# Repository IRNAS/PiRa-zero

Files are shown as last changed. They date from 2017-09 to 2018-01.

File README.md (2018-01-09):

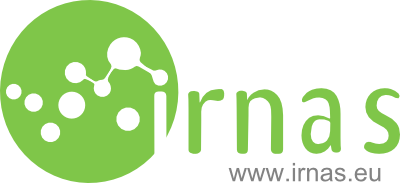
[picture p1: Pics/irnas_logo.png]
irnas_logo

# PiRA zero 
## Power in Responsive Applications HAT for Raspberry Pi with RTC for power saving mode

PiRa zero is a compact shield for power scheduling on Rasppbery Pi and similar devices in solar and wirelessly powered applications. It implements the following key features:

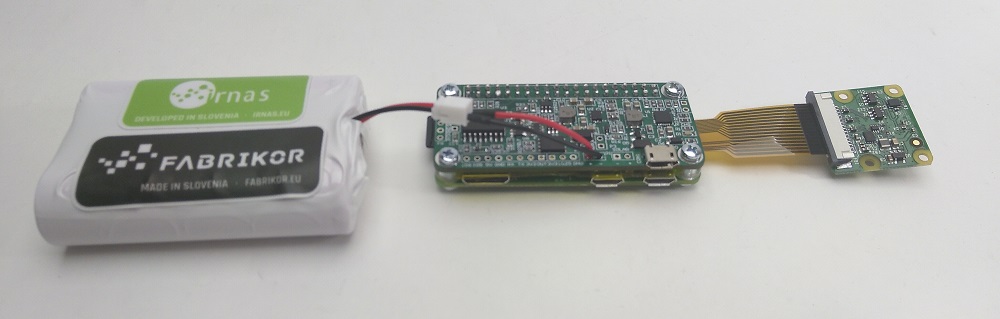
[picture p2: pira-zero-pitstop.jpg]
pira_image


## Features

* single cell LiPo cell charging of up to 3A (multiple 18650 cells supported) + LifePo4 support
* solar panel charging (Voltaic systems 6W panels in parallel recommended)
* USB charging, compatible with QI wireless chargers
* advanced current limiting, to support wide array of chargers
* precise charging control via i2c (BQ24296)
* battery temperature protection with thermistor
* battery reverse polarity protection and fuse (3A)
* high-current battery output mosfet (for 3G or satellite modems)
* LORA RMF95 communication module
* battery voltage precise measurement (MCP3021)
* advanced power scheduling for robust applications:
  * power timer TPL5110 for configurable scheduled boot 1s-7200s or one-time power up on charging
  * S3231 for configurable scheduled boot and timekeeping
  * nfigurable power-up sources
  * ower-up on charging
  * ower-up from power timer
  * ower-up from RTC
  * ower-up from self-enable (external CPU signal)
 
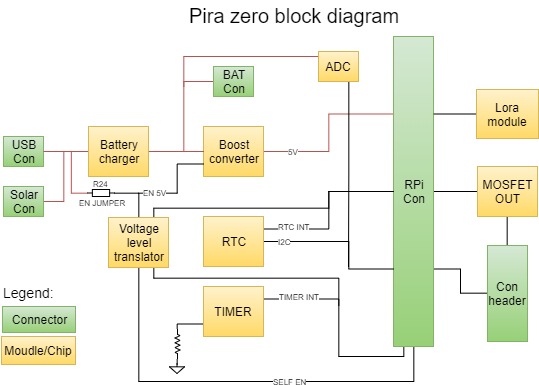
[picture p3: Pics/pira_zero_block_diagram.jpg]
pira_block_diagram


## Connector pinout

 * All ground pins connected, UART, SPI pins connected
 * Pin 1 - 3V3 - from Pi to board
 * Pin 2 - 5V - from board to Pi
 * Pin 3 - SDA
 * Pin 4 - 5V - from board to Pi
 * Pin 5 - SCL
 * Pin 7 - BCM 4 - RTC-Reset- output, reset RTC if needed
 * Pin 11 - BCM 17 - Timer-EN - input, detect wake-up from RTC
 * Pin 12 - BCM 18 - CPU self-enable - output, keep high until shutdown
 * Pin 13 - BCM 27 - Timer done - output, set high to signal timer to power off
 * Pin 15 - BCM 22 - RTC-EN - input, detect wake-up from RTC
 * Pin 16 - BCM 23 - GPO-FET - output, enable mosfet output
 * Pin 22 - BCM 25 - GPIO BCM25 - available at header
 * Pin 29 - BCM 5 - GPIO BCM 5 - available at header
 * Pin 31 - BCM 6 - GPIO BCM 6 - available at header
 * Pin 33 - BCM 13 - LORA reset

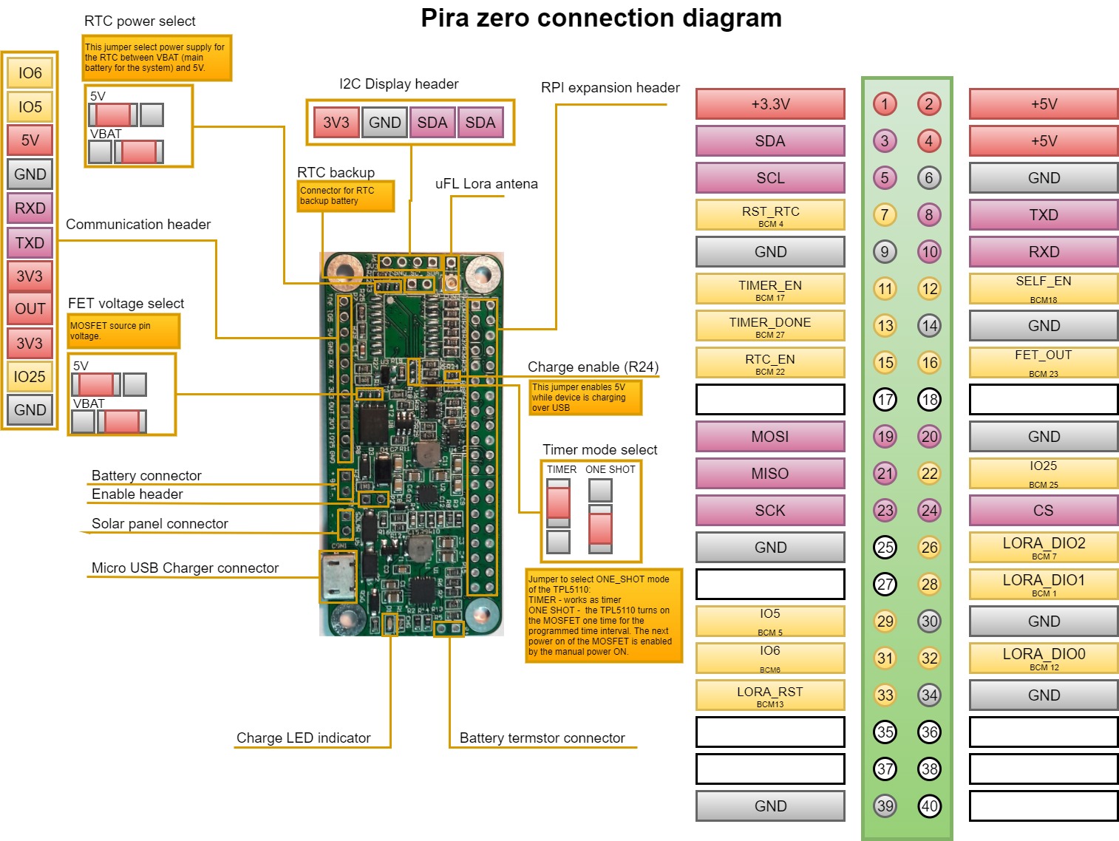
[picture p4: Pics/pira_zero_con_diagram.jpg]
pira_zero_con_diagram


## Power consumption
TODO

---

#### License

All our projects are as usefully open-source as possible.

Hardware including documentation is licensed under [CERN OHL v.1.2. license](http://www.ohwr.org/licenses/cern-ohl/v1.2)

Firmware and software originating from the project is licensed under [GNU GENERAL PUBLIC LICENSE v3](http://www.gnu.org/licenses/gpl-3.0.en.html).

Open data generated by our projects is licensed under [CC0](https://creativecommons.org/publicdomain/zero/1.0/legalcode).

All our websites and additional documentation are licensed under [Creative Commons Attribution-ShareAlike 4 .0 Unported License](https://creativecommons.org/licenses/by-sa/4.0/legalcode).

What this means is that you can use hardware, firmware, software and documentation without paying a royalty and knowing that you'll be able to use your version forever. You are also free to make changes but if you share these changes then you have to do so on the same conditions that you enjoy.

Koruza, GoodEnoughCNC and IRNAS are all names and marks of Institut IRNAS Rače. 
You may use these names and terms only to attribute the appropriate entity as required by the Open Licences referred to above. You may not use them in any other way and in particular you may not use them to imply endorsement or authorization of any hardware that you design, make or sell.

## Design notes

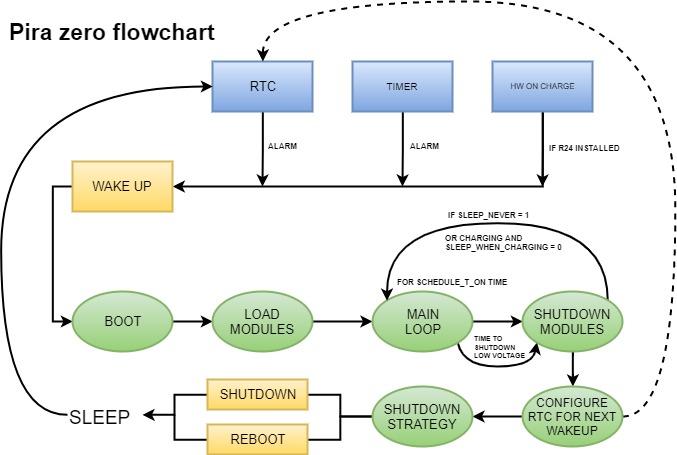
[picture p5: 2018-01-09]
Pics/pira_zero_flowchart.jpg

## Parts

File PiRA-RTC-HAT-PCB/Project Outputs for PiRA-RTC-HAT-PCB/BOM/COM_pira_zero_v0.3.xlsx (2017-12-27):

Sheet: Part List Report
 | Component list |  |  | PiRA RTC HAT
 | Source Data From: | PiRA-RTC-HAT-PCB.PrjPcb |  |  | Contact:
 | Project: | PiRA-RTC-HAT-PCB.PrjPcb
 | Variant: | PiRA-RTC-HAT-PCB_V0.3 |  |  |  |  |  |  | IRNAS
 | Report Date: | 12/11/2017 | 4:28:33 PM |  |  |  |  |  | www.irnas.eu
 | Print Date: | 2017-12-11 | 16:33:48
# | Manufacturer Part Number 1 | Manufacturer 1 | Description | Footprint | Designator | Quantity | Supplier 1 | Supplier Part Number 1 | Supplier Order Qty 1 | Supplier Stock 1 | Supplier Unit Price 1 | Supplier Subtotal 1 | Supplier Currency 1
1 | SI7635DP-T1-GE3 (https://octopart-clicks.com/click/altium?sku=1781668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) | Vishay Siliconix (https://octopart-clicks.com/click/altium?sku=1781668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) | MOSFET P-CH 20V 40A PPAK SO-8 | PG-TSDSON-8 | T2 | 1 | Farnell | 1781668 (https://octopart-clicks.com/click/altium?sku=1781668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) | 20 | 527 | 1.20 | 24.00 | EUR
2 | RS1J-E3/5AT (https://octopart-clicks.com/click/altium?sku=9550143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) | Vishay Semiconductors (https://octopart-clicks.com/click/altium?sku=9550143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) | VISHAY - RS1J-E3/61T.. - DIODE, FAST, 1A, 600V, SMD | SMC/DO-214AC | D4 | 1 | Farnell | 9550143 (https://octopart-clicks.com/click/altium?sku=9550143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) | 20 | 5536 | 0.18 | 3.66 | EUR
3 | SE30AFG-M3/6A (https://octopart-clicks.com/click/altium?sku=2313878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) | Vishay Semiconductors (https://octopart-clicks.com/click/altium?sku=2313878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) | VISHAY - SE30AFG-M3/6A - RECTIFIER, ESD, 400V, 3A, DO-221AC | SODFL127P600-8N | D5, D7 | 2 | Farnell | 2313878 (https://octopart-clicks.com/click/altium?sku=2313878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) | 40 | 11034 | 0.11 | 4.32 | EUR
4 | MMBT3904 (https://octopart-clicks.com/click/altium?sku=9846727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) | Vishay Intertechnology (https://octopart-clicks.com/click/altium?sku=9846727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) | ON SEMICONDUCTOR/FAIRCHILD - MMBT3904 - TRANSISTOR, NPN, SOT-23 | SOT23127P600-8N | T1 | 1 | Farnell | 9846727 (https://octopart-clicks.com/click/altium?sku=9846727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) | 20 | 94908 | 0.18 | 3.58 | EUR
5 | RCA060310R0FKEA (https://octopart-clicks.com/click/altium?sku=2616585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) | Vishay Dale (https://octopart-clicks.com/click/altium?sku=2616585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) | VISHAY - RCA060310R0FKEA - RES, AUTO, THICK FILM, 10R, 1%, 0603 | RES0603 | R30 | 1 | Farnell | 2616585 (https://octopart-clicks.com/click/altium?sku=2616585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) | 20 | 3016 | 0.09 | 1.89 | EUR
6 | CRCW0603169KFKEA (https://octopart-clicks.com/click/altium?sku=2138521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) | Vishay (https://octopart-clicks.com/click/altium?sku=2138521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) | VISHAY - CRCW0603169KFKEA. - RES, THICK FILM, 169K, 1%, 0.1W, 0603 | RES0603 | R31 | 1 | Farnell | 2138521 (https://octopart-clicks.com/click/altium?sku=2138521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) | 20 | 4627 | 0.04 | 0.90 | EUR
7 | BQ24296RGET (https://octopart-clicks.com/click/altium?sku=2373541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) | Texas Instruments (https://octopart-clicks.com/click/altium?sku=2373541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) | IC LI+ CHARGER PWR MGMT 24VQFN | QFN4x4 | U1 | 1 | Farnell | 2373541 (https://octopart-clicks.com/click/altium?sku=2373541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) | 20 | 309 | 2.25 | 45.00 | EUR
8 | TPL5110DDCT (https://octopart-clicks.com/click/altium?sku=2471145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) | Texas Instruments (https://octopart-clicks.com/click/altium?sku=2471145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) | TEXAS INSTRUMENTS - TPL5110DDCT - NANO TIMER, SINGLE, 5.5V, SOT-23-6 | SOT236 | U8 | 1 | Farnell | 2471145 (https://octopart-clicks.com/click/altium?sku=2471145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) | 20 | 352 | 0.81 | 16.30 | EUR
9 | MINISMDC150F/24-2 (https://octopart-clicks.com/click/altium?sku=1345929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) | TE Connectivity (https://octopart-clicks.com/click/altium?sku=1345929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) | LITTELFUSE - MINISMDC150F/24-2 - POLYSWITCH, SMD, 1812, 1.5A | Chip2PinSM127P600-8N | F1 | 1 | Farnell | 1345929 (https://octopart-clicks.com/click/altium?sku=1345929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) | 20 | 2780 | 0.52 | 10.35 | EUR
10 | 2N7002,215 (https://octopart-clicks.com/click/altium?sku=1510761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) | NXP Semiconductors (https://octopart-clicks.com/click/altium?sku=1510761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) | NEXPERIA - 2N7002,215 - MOSFET,N CH, 60V,0.3A,SOT23 | SOT23127P600-8N | T3 | 1 | Farnell | 1510761 (https://octopart-clicks.com/click/altium?sku=1510761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) | 20 | 18508 | 0.11 | 2.21 | EUR
11 | FDSD0420-H-1R5M=P3 (https://octopart-clicks.com/click/altium?sku=2530091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) | Murata (https://octopart-clicks.com/click/altium?sku=2530091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) | MURATA - FDSD0420-H-1R5M=P3 - INDUCTOR, SHIELDED, 1.5UH, 5.1A, 20% | FDSD0402 | L1, L2 | 2 | Farnell | 2530091 (https://octopart-clicks.com/click/altium?sku=2530091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) | 40 | 1328 | 0.89 | 35.48 | EUR
12 | GRM188R61C475KAAJD (https://octopart-clicks.com/click/altium?sku=2611924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) | Murata (https://octopart-clicks.com/click/altium?sku=2611924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) | MURATA - GRM188R61C475KAAJD - CAP, MLCC, X5R, 4.7UF, 16V, 0603 | CAP0603 | C2 | 1 | Farnell | 2611924 (https://octopart-clicks.com/click/altium?sku=2611924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) | 20 | 6778 | 0.18 | 3.68 | EUR
13 | MCWR06X1000FTL (https://octopart-clicks.com/click/altium?sku=2447227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) | Multicomp (https://octopart-clicks.com/click/altium?sku=2447227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) | MULTICOMP - MC0063W06031100R - RES, THICK FILM, 100R, 1%, 0.063W, 0603 | RES0603 | R18, R27 | 2 | Farnell | 2447227 (https://octopart-clicks.com/click/altium?sku=2447227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) | 40 | 75390 | 0.0034 | 0.14 | EUR
14 | MCCA000249 (https://octopart-clicks.com/click/altium?sku=1759116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) | Multicomp (https://octopart-clicks.com/click/altium?sku=1759116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) | MULTICOMP - MC0603B473K500CT - CAP, MLCC, X7R, 47NF, 50V, 0603 | CAP0603 | C3 | 1 | Farnell | 1759116 (https://octopart-clicks.com/click/altium?sku=1759116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) | 20 | 18040 | 0.01 | 0.24 | EUR
15 | MCCA000536 (https://octopart-clicks.com/click/altium?sku=1759415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) | Multicomp (https://octopart-clicks.com/click/altium?sku=1759415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) | MULTICOMP - MC0805X226M6R3CT - CAP, MLCC, X5R, 22UF, 0805 | CAP0805 | C7, C8, C9, C10 | 4 | Farnell | 1759415 (https://octopart-clicks.com/click/altium?sku=1759415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) | 80 | 185208 | 0.14 | 11.38 | EUR
16 | MCMR06X103JTL (https://octopart-clicks.com/click/altium?sku=2073356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) | Multicomp (https://octopart-clicks.com/click/altium?sku=2073356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) | MULTICOMP - MCMR06X103 JTL - RES, CERAMIC, 10K, 5%, 0.1W, 0603 | RES0603 | R5, R10, R11, R12, R16, R20, R21, R22, R35, R36, R37, R39, R40 | 13 | Farnell | 2073356 (https://octopart-clicks.com/click/altium?sku=2073356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) | 260 | 6771 | 0.004 | 1.04 | EUR
17 | MCMR06X104JTL (https://octopart-clicks.com/click/altium?sku=2073357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) | Multicomp (https://octopart-clicks.com/click/altium?sku=2073357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) | MULTICOMP - MCMR06X104 JTL - RES, CERAMIC, 100K, 5%, 0.1W, 0603 | RES0603 | R17, R19, R38 | 3 | Farnell | 2073357 (https://octopart-clicks.com/click/altium?sku=2073357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) | 60 | 10259 | 0.01 | 0.41 | EUR
18 | MCMR06X4702FTL (https://octopart-clicks.com/click/altium?sku=2073510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) | Multicomp (https://octopart-clicks.com/click/altium?sku=2073510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) | MULTICOMP - MCMR06X4702FTL - RES, CERAMIC, 47K, 1%, 0.1W, 0603 | RES0603 | R23, R25 | 2 | Farnell | 2073510 (https://octopart-clicks.com/click/altium?sku=2073510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) | 40 | 9589 | 0.01 | 0.36 | EUR
19 | MCMR06X471JTL (https://octopart-clicks.com/click/altium?sku=2073513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) | Multicomp (https://octopart-clicks.com/click/altium?sku=2073513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) | MULTICOMP - MCMR06X471 JTL - RES, CERAMIC, 470R, 5%, 0.1W, 0603 | RES0603 | R1, R13 | 2 | Farnell | 2073513 (https://octopart-clicks.com/click/altium?sku=2073513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) | 40 | 1881 | 0.01 | 0.34 | EUR
20 | MCMR06X5601FTL (https://octopart-clicks.com/click/altium?sku=2073537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) | Multicomp (https://octopart-clicks.com/click/altium?sku=2073537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) | MULTICOMP - MCMR06X5601FTL - RES, CERAMIC, 5K6, 1%, 0.1W, 0603 | RES0603 | R6 | 1 | Farnell | 2073537 (https://octopart-clicks.com/click/altium?sku=2073537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) | 20 | 7455 | 0.01 | 0.18 | EUR
21 | MCWR06W1204FTL (https://octopart-clicks.com/click/altium?sku=2447286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) | Multicomp (https://octopart-clicks.com/click/altium?sku=2447286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) | MULTICOMP - MCWR06W1204FTL - RES, THICK FILM, 1.2MOHM, 1%, 0.1W | RES0603 | R34 | 1 | Farnell | 2447286 (https://octopart-clicks.com/click/altium?sku=2447286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) | 20 | 200 | 0.0046 | 0.09 | EUR
22 | MCWR06X1503FTL (https://octopart-clicks.com/click/altium?sku=2447254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) | Multicomp (https://octopart-clicks.com/click/altium?sku=2447254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) | MULTICOMP - MCWR06X1503FTL - RES, THICK FILM, 150KOHM, 1%, 0.1W | RES0603 | R8 | 1 | Farnell | 2447254 (https://octopart-clicks.com/click/altium?sku=2447254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) | 20 | 8900 | 0.0033 | 0.07 | EUR
23 | MCWR06X2200FTL (https://octopart-clicks.com/click/altium?sku=2447298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) | Multicomp (https://octopart-clicks.com/click/altium?sku=2447298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) | MULTICOMP - MCWR06X2200FTL - RES, THICK FILM, 220R, 1%, 0.1W, 0603 | RES0603 | R7 | 1 | Farnell | 2447298 (https://octopart-clicks.com/click/altium?sku=2447298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) | 20 | 267443 | 0.0034 | 0.07 | EUR
24 | MCWR06X3302FTL (https://octopart-clicks.com/click/altium?sku=2447342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) | Multicomp (https://octopart-clicks.com/click/altium?sku=2447342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) | MULTICOMP - MCWR06X3302FTL - RES, THICK FILM, 33K, 1%, 0.1W, 0603 | RES0603 | R15 | 1 | Farnell | 2447342 (https://octopart-clicks.com/click/altium?sku=2447342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) | 20 | 145120 | 0.0033 | 0.07 | EUR
25 | MCWR06X3901FTL (https://octopart-clicks.com/click/altium?sku=2447363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) | Multicomp (https://octopart-clicks.com/click/altium?sku=2447363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) | MULTICOMP - MCWR06X3901FTL - RES, THICK FILM, 3K9, 1%, 0.1W, 0603 | RES0603 | R4 | 1 | Farnell | 2447363 (https://octopart-clicks.com/click/altium?sku=2447363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) | 20 | 60290 | 0.0034 | 0.07 | EUR
26 | MCWR06X4703FTL (https://octopart-clicks.com/click/altium?sku=2447373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) | Multicomp (https://octopart-clicks.com/click/altium?sku=2447373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) | MULTICOMP - MCWR06X4703FTL - RES, THICK FILM, 470K, 1%, 0.1W, 0603 | RES0603 | R9, R26, R29, R32, R33 | 5 | Farnell | 2447373 (https://octopart-clicks.com/click/altium?sku=2447373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) | 100 | 61114 | 0.002 | 0.20 | EUR
27 | MC0603X105K100CT (https://octopart-clicks.com/click/altium?sku=1759399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) | Multicomp (https://octopart-clicks.com/click/altium?sku=1759399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) | MURATA - GRM188R61H105KAALD - CAP, MLCC, X5R, 1UF, 50V, 0603 | CAP0603 | C15 | 1 | Farnell | 1759399 (https://octopart-clicks.com/click/altium?sku=1759399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) | 20 | 93649 | 0.03 | 0.58 | EUR
28 | MC0805X106K160CT (https://octopart-clicks.com/click/altium?sku=2320856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) | Multicomp (https://octopart-clicks.com/click/altium?sku=2320856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) | TDK - CGA4J1X5R1C106K125AC - CAP, MLCC, X5R, 10UF, 16V, 0805 | CAP0805 | C1, C4, C5, C6, C11 | 5 | Farnell | 2320856 (https://octopart-clicks.com/click/altium?sku=2320856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) | 100 | 117558 | 0.06 | 5.70 | EUR
29 | MCP3021A5T-E/OT (https://octopart-clicks.com/click/altium?sku=1332097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) | Microchip (https://octopart-clicks.com/click/altium?sku=1332097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) | MICROCHIP - MCP3021A5T-E/OT - 10BIT ADC, I2C, 1CH, SMD, SOT-23A-5 | SOT23127P600-8N - duplicate | U4 | 1 | Farnell | 1332097 (https://octopart-clicks.com/click/altium?sku=1332097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) | 20 | 9267 | 0.93 | 18.54 | EUR
30 | DS3231M+TRL (https://octopart-clicks.com/click/altium?sku=2515485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) | Maxim (https://octopart-clicks.com/click/altium?sku=2515485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) | MAXIM INTEGRATED PRODUCTS - DS3231M+TRL - RTC, I2C, WSOIC-16 | SOIC127P1030X265-16N | U3 | 1 | Farnell | 2515485 (https://octopart-clicks.com/click/altium?sku=2515485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) | 20 | 659 | 6.56 | 131.20 | EUR
31 | Loading... (https://octopart-clicks.com/click/altium?sku=2688519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) | Loading... (https://octopart-clicks.com/click/altium?sku=2688519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) | MURATA - GRM188R71C104KA01J - CAP, MLCC, X7R, 0.1UF, 16V, 0603 | CAP0603 | C12, C13, C14 | 3 | Farnell | 2688519 (https://octopart-clicks.com/click/altium?sku=2688519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) |  |  |  |  | Loading...
32 | Loading... (https://octopart-clicks.com/click/altium?sku=2463510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) | Loading... (https://octopart-clicks.com/click/altium?sku=2463510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) | ON SEMICONDUCTOR - MM3Z3V0T1G - ZENER DIODE, 200MW, 3V, SOD-323 | SOD-323 2L | D2 | 1 | Farnell | 2463510 (https://octopart-clicks.com/click/altium?sku=2463510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) |  |  |  |  | Loading...
33 | Loading... (https://octopart-clicks.com/click/altium?sku=1597-1488-ND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) | Loading... (https://octopart-clicks.com/click/altium?sku=1597-1488-ND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) | RFM95 ULTRA-LONG RANGE TRANSCEIV | Lora_module1 | U7 | 1 | Digi-Key | 1597-1488-ND (https://octopart-clicks.com/click/altium?sku=1597-1488-ND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) |  |  |  |  | Loading...
34 | Loading... (https://octopart-clicks.com/click/altium?sku=2643432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) | Loading... (https://octopart-clicks.com/click/altium?sku=2643432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) | TEXAS INSTRUMENTS - TPS630701RNMT - DC/DC CONV, BUCK-BOOST, 2.4MHZ, VQFN-15 | VQFN TPS | U2 | 1 | Farnell | 2643432 (https://octopart-clicks.com/click/altium?sku=2643432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) |  |  |  |  | Loading...
35 | U.FLRSMT110 (https://octopart-clicks.com/click/altium?sku=1688077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) | Hirose (https://octopart-clicks.com/click/altium?sku=1688077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) | HIROSE(HRS) - U.FL-R-SMT-1(10) - RF COAXIAL, U.FL, STRAIGHT JACK, 50OHM | uFL SMD connector | CON3 | 1 | Farnell | 1688077 (https://octopart-clicks.com/click/altium?sku=1688077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) | 20 | 146416 | 0.65 | 13.00 | EUR
36 | BZT52C6V2 (https://octopart-clicks.com/click/altium?sku=1902438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) | Diodes Zetex (https://octopart-clicks.com/click/altium?sku=1902438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) | DIODES INC. - BZT52C6V2 - DIODE, ZENER, 6.2V, 0.5W, SOD-123 | SOD123 | D6 | 1 | Farnell | 1902438 (https://octopart-clicks.com/click/altium?sku=1902438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) | 20 | 2257 | 0.60 | 11.96 | EUR
37 | 1N4148W-7-F (https://octopart-clicks.com/click/altium?sku=1776392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) | Diodes (https://octopart-clicks.com/click/altium?sku=1776392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) | DIODES INC. - 1N4148W-7-F. - DIODE, SWITCH, 300MA, 100V,SOD123 | SOD123 | D3 | 1 | Farnell | 1776392 (https://octopart-clicks.com/click/altium?sku=1776392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) | 20 | 142248 | 0.41 | 8.26 | EUR
38 | DMG6602SVT (https://octopart-clicks.com/click/altium?sku=2061522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) | Diodes (https://octopart-clicks.com/click/altium?sku=2061522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) | DIODES INC. - DMG6602SVT - MOSFET, NP CH, , 30V, 3.4, ATSOT23 | TSOT26 | U5, U6 | 2 | Farnell | 2061522 (https://octopart-clicks.com/click/altium?sku=2061522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) | 40 | 3903 | 0.39 | 15.64 | EUR
39 | HSMS-C190 (https://octopart-clicks.com/click/altium?sku=2497356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) | Broadcom Avago (https://octopart-clicks.com/click/altium?sku=2497356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) | BROADCOM LIMITED - HSMS-C190 - LED, RED, 10MCD, 626NM | LED0603 | D1 | 1 | Farnell | 2497356 (https://octopart-clicks.com/click/altium?sku=2497356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) | 20 | 4037 | 0.50 | 9.94 | EUR
40 | CR0603-J/-000ELF (https://octopart-clicks.com/click/altium?sku=2008343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) | Bourns (https://octopart-clicks.com/click/altium?sku=2008343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) | BOURNS - CR0603-J/-000ELF - RES, THICK FILM, 0R, 5%, 0.1W, 0603 | RES0603 | R2, R3, R14, R24, R28 | 5 | Farnell | 2008343 (https://octopart-clicks.com/click/altium?sku=2008343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) | 100 | 18712 | 0.02 | 1.64 | EUR
 |  |  |  |  |  | 77 |  |  | 1420 |  |  | 382.4644
Approved |  |  |  | Notes
 |  |  |  | pcs: |  | 20 |  | Total |  | 382.4644 |  | EUR
 |  |  |  |  |  |  |  | Price for 1pcs |  | 19.12 |  | EUR

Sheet: Project Information
Project Full Path | C:\Users\vojislav\Documents\PiRA-RTC-HAT\PiRA-RTC-HAT-PCB\PiRA-RTC-HAT-PCB.PrjPcb
Project Filename | PiRA-RTC-HAT-PCB.PrjPcb
Variant Name | PiRA-RTC-HAT-PCB_V0.3
Data-Source Filename | PiRA-RTC-HAT-PCB.PrjPcb
Data-Source Full Path | C:\Users\vojislav\Documents\PiRA-RTC-HAT\PiRA-RTC-HAT-PCB\PiRA-RTC-HAT-PCB.PrjPcb
Title | <Parameter Title not found>
Total Quantity | 77
Report Time | 4:28:33 PM
Report Date | 12/11/2017
Report Date & Tine | 12/11/2017 4:28:33 PM
Output Name | Bill of Materials production
Output Type | BOM_PartType
Output Generator Name | BOM
Output Generator Description | Bill of Materials

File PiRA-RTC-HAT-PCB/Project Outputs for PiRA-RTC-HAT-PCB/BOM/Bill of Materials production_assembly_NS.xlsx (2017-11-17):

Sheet: Part List Report
 | Component list |  |  | PiRA RTC HAT
 | Source Data From: | PiRA-RTC-HAT-PCB.PrjPcb |  |  | Contact:
 | Project: | PiRA-RTC-HAT-PCB.PrjPcb
 | Variant: | Variant of PiRA-RTC-HAT-PCB_assembly_NS |  |  |  |  |  |  | IRNAS
 | Report Date: | 11/09/2017 | 3:02:10 PM |  |  |  |  |  | www.irnas.eu
 | Print Date: | 2017-11-09 | 15:08:07
# | Manufacturer Part Number 1 | Manufacturer 1 | Description | Footprint | Designator | Quantity | Supplier 1 | Supplier Part Number 1 | Supplier Order Qty 1 | Supplier Stock 1 | Supplier Unit Price 1 | Supplier Subtotal 1 | Supplier Currency 1
1 | RS1J-E3/5AT (https://octopart-clicks.com/click/altium?sku=9550143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) | Vishay Semiconductors (https://octopart-clicks.com/click/altium?sku=9550143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) | VISHAY - RS1J-E3/61T.. - DIODE, FAST, 1A, 600V, SMD | SMC/DO-214AC | D4 | 1 | Farnell | 9550143 (https://octopart-clicks.com/click/altium?sku=9550143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) | 20 | 5536 | 0.18 | 3.64 | EUR
2 | SE30AFG-M3/6A (https://octopart-clicks.com/click/altium?sku=2313878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) | Vishay Semiconductors (https://octopart-clicks.com/click/altium?sku=2313878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) | VISHAY - SE30AFG-M3/6A - RECTIFIER, ESD, 400V, 3A, DO-221AC | SODFL127P600-8N | D5 | 1 | Farnell | 2313878 (https://octopart-clicks.com/click/altium?sku=2313878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) | 20 | 13454 | 0.35 | 6.92 | EUR
3 | RCA060310R0FKEA (https://octopart-clicks.com/click/altium?sku=2616585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) | Vishay Dale (https://octopart-clicks.com/click/altium?sku=2616585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) | VISHAY - RCA060310R0FKEA - RES, AUTO, THICK FILM, 10R, 1%, 0603 | RES0603 | R30 | 1 | Farnell | 2616585 (https://octopart-clicks.com/click/altium?sku=2616585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) | 20 | 3286 | 0.15 | 2.96 | EUR
4 | CRCW0603169KFKEA (https://octopart-clicks.com/click/altium?sku=2138521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) | Vishay (https://octopart-clicks.com/click/altium?sku=2138521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) | VISHAY - CRCW0603169KFKEA. - RES, THICK FILM, 169K, 1%, 0.1W, 0603 | RES0603 | R31 | 1 | Farnell | 2138521 (https://octopart-clicks.com/click/altium?sku=2138521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) | 20 | 5697 | 0.04 | 0.84 | EUR
5 | BQ24296RGET (https://octopart-clicks.com/click/altium?sku=2373541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) | Texas Instruments (https://octopart-clicks.com/click/altium?sku=2373541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) | IC LI+ CHARGER PWR MGMT 24VQFN | QFN4x4 | U1 | 1 | Farnell | 2373541 (https://octopart-clicks.com/click/altium?sku=2373541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) | 20 | 418 | 2.25 | 45.00 | EUR
6 | TPL5110DDCT (https://octopart-clicks.com/click/altium?sku=2471145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) | Texas Instruments (https://octopart-clicks.com/click/altium?sku=2471145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) | TEXAS INSTRUMENTS - TPL5110DDCT - NANO TIMER, SINGLE, 5.5V, SOT-23-6 | SOT236 | U8 | 1 | Farnell | 2471145 (https://octopart-clicks.com/click/altium?sku=2471145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) | 20 | 1202 | 0.81 | 16.30 | EUR
7 | MINISMDC150F/24-2 (https://octopart-clicks.com/click/altium?sku=1345929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) | TE Connectivity (https://octopart-clicks.com/click/altium?sku=1345929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) | LITTELFUSE - MINISMDC150F/24-2 - POLYSWITCH, SMD, 1812, 1.5A | Chip2PinSM127P600-8N | F1 | 1 | Farnell | 1345929 (https://octopart-clicks.com/click/altium?sku=1345929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) | 20 | 2780 | 0.51 | 10.29 | EUR
8 | 2N7002,215 (https://octopart-clicks.com/click/altium?sku=1510761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) | NXP Semiconductors (https://octopart-clicks.com/click/altium?sku=1510761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) | NEXPERIA - 2N7002,215 - MOSFET,N CH, 60V,0.3A,SOT23 | SOT23127P600-8N | T3 | 1 | Farnell | 1510761 (https://octopart-clicks.com/click/altium?sku=1510761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) | 20 | 18508 | 0.11 | 2.19 | EUR
9 | MMBT3904 (https://octopart-clicks.com/click/altium?sku=9846727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) | NTE Electronics (https://octopart-clicks.com/click/altium?sku=9846727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) | ON SEMICONDUCTOR/FAIRCHILD - MMBT3904 - TRANSISTOR, NPN, SOT-23 | SOT23127P600-8N | T1 | 1 | Farnell | 9846727 (https://octopart-clicks.com/click/altium?sku=9846727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) | 20 | 27322 | 0.04 | 0.82 | EUR
10 | FDSD0420-H-1R5M=P3 (https://octopart-clicks.com/click/altium?sku=2530091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) | Murata (https://octopart-clicks.com/click/altium?sku=2530091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) | MURATA - FDSD0420-H-1R5M=P3 - INDUCTOR, SHIELDED, 1.5UH, 5.1A, 20% | FDSD0402 | L1, L2 | 2 | Farnell | 2530091 (https://octopart-clicks.com/click/altium?sku=2530091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) | 40 | 1393 | 0.80 | 31.88 | EUR
11 | GRM188R61C475KAAJD (https://octopart-clicks.com/click/altium?sku=2611924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) | Murata (https://octopart-clicks.com/click/altium?sku=2611924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) | MURATA - GRM188R61C475KAAJD - CAP, MLCC, X5R, 4.7UF, 16V, 0603 | CAP0603 | C2 | 1 | Farnell | 2611924 (https://octopart-clicks.com/click/altium?sku=2611924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) | 20 | 4471 | 0.18 | 3.68 | EUR
12 | GRM188R61H105KAALD (https://octopart-clicks.com/click/altium?sku=1845736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) | Murata (https://octopart-clicks.com/click/altium?sku=1845736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) | MURATA - GRM188R61H105KAALD - CAP, MLCC, X5R, 1UF, 50V, 0603 | CAP0603 | C15 | 1 | Farnell | 1845736 (https://octopart-clicks.com/click/altium?sku=1845736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) | 20 | 11937 | 0.19 | 3.78 | EUR
13 | MC0.063W06031%100R, MCWR06X1000FTL (https://octopart-clicks.com/click/altium?manufacturer=Multicomp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) | Multicomp (https://octopart-clicks.com/click/altium?manufacturer=Multicomp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) | MULTICOMP - MC0063W06031100R - RES, THICK FILM, 100R, 1%, 0.063W, 0603 | RES0603 | R18, R27 | 2 | Farnell | 2447227 (https://octopart-clicks.com/click/altium?manufacturer=Multicomp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) | 40 | 123933 | 0.0032 | 0.13 | EUR
14 | MC0603B473K500CT (https://octopart-clicks.com/click/altium?sku=1759116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) | Multicomp (https://octopart-clicks.com/click/altium?sku=1759116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) | MULTICOMP - MC0603B473K500CT - CAP, MLCC, X7R, 47NF, 50V, 0603 | CAP0603 | C3 | 1 | Farnell | 1759116 (https://octopart-clicks.com/click/altium?sku=1759116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) | 20 | 21567 | 0.02 | 0.41 | EUR
15 | MCCA000536 (https://octopart-clicks.com/click/altium?sku=1759415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) | Multicomp (https://octopart-clicks.com/click/altium?sku=1759415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) | MULTICOMP - MC0805X226M6R3CT - CAP, MLCC, X5R, 22UF, 0805 | CAP0805 | C7, C8, C9, C10 | 4 | Farnell | 1759415 (https://octopart-clicks.com/click/altium?sku=1759415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) | 80 | 185208 | 0.14 | 11.31 | EUR
16 | MCMR06X103JTL (https://octopart-clicks.com/click/altium?sku=2073356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) | Multicomp (https://octopart-clicks.com/click/altium?sku=2073356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) | MULTICOMP - MCMR06X103 JTL - RES, CERAMIC, 10K, 5%, 0.1W, 0603 | RES0603 | R5, R10, R11, R12, R16, R20, R21, R22 | 8 | Farnell | 2073356 (https://octopart-clicks.com/click/altium?sku=2073356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) | 160 | 10041 | 0.0041 | 0.66 | EUR
17 | MCMR06X104JTL (https://octopart-clicks.com/click/altium?sku=2073357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) | Multicomp (https://octopart-clicks.com/click/altium?sku=2073357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) | MULTICOMP - MCMR06X104 JTL - RES, CERAMIC, 100K, 5%, 0.1W, 0603 | RES0603 | R17, R19 | 2 | Farnell | 2073357 (https://octopart-clicks.com/click/altium?sku=2073357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) | 40 | 16958 | 0.01 | 0.28 | EUR
18 | MCMR06X4702FTL (https://octopart-clicks.com/click/altium?sku=2073510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) | Multicomp (https://octopart-clicks.com/click/altium?sku=2073510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) | MULTICOMP - MCMR06X4702FTL - RES, CERAMIC, 47K, 1%, 0.1W, 0603 | RES0603 | R23, R25 | 2 | Farnell | 2073510 (https://octopart-clicks.com/click/altium?sku=2073510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) | 40 | 11239 | 0.01 | 0.36 | EUR
19 | MCMR06X471JTL (https://octopart-clicks.com/click/altium?sku=2073513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) | Multicomp (https://octopart-clicks.com/click/altium?sku=2073513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) | MULTICOMP - MCMR06X471 JTL - RES, CERAMIC, 470R, 5%, 0.1W, 0603 | RES0603 | R1, R13 | 2 | Farnell | 2073513 (https://octopart-clicks.com/click/altium?sku=2073513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) | 40 | 1511 | 0.0047 | 0.19 | EUR
20 | MCMR06X5601FTL (https://octopart-clicks.com/click/altium?sku=2073537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) | Multicomp (https://octopart-clicks.com/click/altium?sku=2073537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) | MULTICOMP - MCMR06X5601FTL - RES, CERAMIC, 5K6, 1%, 0.1W, 0603 | RES0603 | R6 | 1 | Farnell | 2073537 (https://octopart-clicks.com/click/altium?sku=2073537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) | 20 | 2985 | 0.01 | 0.11 | EUR
21 | MCWR06W1204FTL (https://octopart-clicks.com/click/altium?sku=2447286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) | Multicomp (https://octopart-clicks.com/click/altium?sku=2447286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) | MULTICOMP - MCWR06W1204FTL - RES, THICK FILM, 1.2MOHM, 1%, 0.1W | RES0603 | R34 | 1 | Farnell | 2447286 (https://octopart-clicks.com/click/altium?sku=2447286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) | 20 | 3590 | 0.0046 | 0.09 | EUR
22 | MCWR06X1503FTL (https://octopart-clicks.com/click/altium?sku=2447254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) | Multicomp (https://octopart-clicks.com/click/altium?sku=2447254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) | MULTICOMP - MCWR06X1503FTL - RES, THICK FILM, 150KOHM, 1%, 0.1W | RES0603 | R8 | 1 | Farnell | 2447254 (https://octopart-clicks.com/click/altium?sku=2447254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) | 20 | 4775 | 0.0034 | 0.07 | EUR
23 | MCWR06X2200FTL (https://octopart-clicks.com/click/altium?sku=2447298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) | Multicomp (https://octopart-clicks.com/click/altium?sku=2447298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) | MULTICOMP - MCWR06X2200FTL - RES, THICK FILM, 220R, 1%, 0.1W, 0603 | RES0603 | R7 | 1 | Farnell | 2447298 (https://octopart-clicks.com/click/altium?sku=2447298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) | 20 | 126041 | 0.0021 | 0.04 | EUR
24 | MCWR06X3302FTL (https://octopart-clicks.com/click/altium?sku=2447342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) | Multicomp (https://octopart-clicks.com/click/altium?sku=2447342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) | MULTICOMP - MCWR06X3302FTL - RES, THICK FILM, 33K, 1%, 0.1W, 0603 | RES0603 | R15 | 1 | Farnell | 2447342 (https://octopart-clicks.com/click/altium?sku=2447342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) | 20 | 77040 | 0.0035 | 0.07 | EUR
25 | MCWR06X3901FTL (https://octopart-clicks.com/click/altium?sku=2447363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) | Multicomp (https://octopart-clicks.com/click/altium?sku=2447363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) | MULTICOMP - MCWR06X3901FTL - RES, THICK FILM, 3K9, 1%, 0.1W, 0603 | RES0603 | R4 | 1 | Farnell | 2447363 (https://octopart-clicks.com/click/altium?sku=2447363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) | 20 | 50445 | 0.0036 | 0.07 | EUR
26 | MCWR06X4703FTL (https://octopart-clicks.com/click/altium?sku=2447373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) | Multicomp (https://octopart-clicks.com/click/altium?sku=2447373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) | MULTICOMP - MCWR06X4703FTL - RES, THICK FILM, 470K, 1%, 0.1W, 0603 | RES0603 | R9, R26, R29, R32, R33 | 5 | Farnell | 2447373 (https://octopart-clicks.com/click/altium?sku=2447373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) | 100 | 47464 | 0.0021 | 0.21 | EUR
27 | MC0805X106K160CT (https://octopart-clicks.com/click/altium?sku=2320856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) | Multicomp (https://octopart-clicks.com/click/altium?sku=2320856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) | TDK - CGA4J1X5R1C106K125AC - CAP, MLCC, X5R, 10UF, 16V, 0805 | CAP0805 | C1, C4, C5, C6, C11 | 5 | Farnell | 2320856 (https://octopart-clicks.com/click/altium?sku=2320856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) | 100 | 131369 | 0.06 | 5.61 | EUR
28 | MCP3021A5T-E/OT (https://octopart-clicks.com/click/altium?sku=1332097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) | Microchip (https://octopart-clicks.com/click/altium?sku=1332097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) | MICROCHIP - MCP3021A5T-E/OT - 10BIT ADC, I2C, 1CH, SMD, SOT-23A-5 | SOT23127P600-8N - duplicate | U4 | 1 | Farnell | 1332097 (https://octopart-clicks.com/click/altium?sku=1332097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) | 20 | 7151 | 0.93 | 18.54 | EUR
29 | Loading... (https://octopart-clicks.com/click/altium?sku=2646394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) | Loading... (https://octopart-clicks.com/click/altium?sku=2646394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) | INFINEON - BSZ120P03NS3GATMA1 - MOSFET, P-CH, -30V, -40A, PG-TSDSON-8 | PG-TSDSON-8 | T2 | 1 | Farnell | 2646394 (https://octopart-clicks.com/click/altium?sku=2646394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) | 20 | 1035 | 0.79 |  | Loading...
30 | Loading... (https://octopart-clicks.com/click/altium?sku=2688519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) | Loading... (https://octopart-clicks.com/click/altium?sku=2688519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) | MURATA - GRM188R71C104KA01J - CAP, MLCC, X7R, 0.1UF, 16V, 0603 | CAP0603 | C12, C13, C14 | 3 | Farnell | 432210 (https://octopart-clicks.com/click/altium?sku=2688519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) | 60 | 1746 |  |  | Loading...
31 | Loading... (https://octopart-clicks.com/click/altium?sku=2463510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) | Loading... (https://octopart-clicks.com/click/altium?sku=2463510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) | ON SEMICONDUCTOR - MM3Z3V0T1G - ZENER DIODE, 200MW, 3V, SOD-323 | SOD-323 2L | D2 | 1 | Farnell | 2463510 (https://octopart-clicks.com/click/altium?sku=2463510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) | 20 | 3381 |  |  | Loading...
32 | Loading... (https://octopart-clicks.com/click/altium?sku=2643432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) | Loading... (https://octopart-clicks.com/click/altium?sku=2643432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) | TEXAS INSTRUMENTS - TPS630701RNMT - DC/DC CONV, BUCK-BOOST, 2.4MHZ, VQFN-15 | VQFN TPS | U2 | 1 | Farnell | 2643432 (https://octopart-clicks.com/click/altium?sku=2643432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) | 20 | 449 |  |  | Loading...
33 | U.FLRSMT110 (https://octopart-clicks.com/click/altium?sku=1688077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) | Hirose (https://octopart-clicks.com/click/altium?sku=1688077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) | HIROSE(HRS) - U.FL-R-SMT-1(10) - RF COAXIAL, U.FL, STRAIGHT JACK, 50OHM | uFL SMD connector | CON2 | 1 | Farnell | 1688077 (https://octopart-clicks.com/click/altium?sku=1688077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) | 20 | 121730 | 0.65 | 13.00 | EUR
34 | BZT52C6V2 (https://octopart-clicks.com/click/altium?sku=1902438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) | Diodes Zetex (https://octopart-clicks.com/click/altium?sku=1902438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) | DIODES INC. - BZT52C6V2 - DIODE, ZENER, 6.2V, 0.5W, SOD-123 | SOD123 | D6 | 1 | Farnell | 1902438 (https://octopart-clicks.com/click/altium?sku=1902438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) | 20 | 4412 | 0.50 | 9.94 | EUR
35 | DMG6602SVT (https://octopart-clicks.com/click/altium?sku=2061522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) | Diodes (https://octopart-clicks.com/click/altium?sku=2061522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) | DIODES INC. - DMG6602SVT - MOSFET, NP CH, , 30V, 3.4, ATSOT23 | TSOT26 | U5, U6 | 2 | Farnell | 2061522 (https://octopart-clicks.com/click/altium?sku=2061522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) | 40 | 4581 | 0.39 | 15.64 | EUR
36 | HSMS-C190 (https://octopart-clicks.com/click/altium?sku=2497356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) | Broadcom Avago (https://octopart-clicks.com/click/altium?sku=2497356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) | BROADCOM LIMITED - HSMS-C190 - LED, RED, 10MCD, 626NM | LED0603 | D1 | 1 | Farnell | 2497356 (https://octopart-clicks.com/click/altium?sku=2497356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) | 20 | 4485 | 0.50 | 9.94 | EUR
37 | CR0603-J/-000ELF (https://octopart-clicks.com/click/altium?sku=2008343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) | Bourns (https://octopart-clicks.com/click/altium?sku=2008343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) | BOURNS - CR0603-J/-000ELF - RES, THICK FILM, 0R, 5%, 0.1W, 0603 | RES0603 | R2, R3, R14, R24, R28 | 5 | Farnell | 2008343 (https://octopart-clicks.com/click/altium?sku=2008343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) | 100 | 17056 | 0.02 | 1.65 | EUR
 |  |  |  |  |  | 67 |  |  | 1340 |  |  | 216.63187
Approved |  |  |  | Notes
 |  |  |  | pcs: |  | 20 |  | Total |  | 216.63187 |  | EUR
 |  |  |  |  |  |  |  | Price for 1pcs |  | 10.83 |  | EUR

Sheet: Project Information
Project Full Path | C:\Users\vojislav\Documents\PiRA-RTC-HAT\PiRA-RTC-HAT-PCB\PiRA-RTC-HAT-PCB.PrjPcb
Project Filename | PiRA-RTC-HAT-PCB.PrjPcb
Variant Name | Variant of PiRA-RTC-HAT-PCB_assembly_NS
Data-Source Filename | PiRA-RTC-HAT-PCB.PrjPcb
Data-Source Full Path | C:\Users\vojislav\Documents\PiRA-RTC-HAT\PiRA-RTC-HAT-PCB\PiRA-RTC-HAT-PCB.PrjPcb
Title | <Parameter Title not found>
Total Quantity | 67
Report Time | 3:02:10 PM
Report Date | 11/09/2017
Report Date & Tine | 11/09/2017 3:02:10 PM
Output Name | Bill of Materials production
Output Type | BOM_PartType
Output Generator Name | BOM
Output Generator Description | Bill of Materials

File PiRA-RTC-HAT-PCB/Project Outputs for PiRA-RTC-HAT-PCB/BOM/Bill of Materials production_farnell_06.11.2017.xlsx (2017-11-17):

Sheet: Part List Report
 | Component list |  |  | PiRA RTC HAT
 | Source Data From: | PiRA-RTC-HAT-PCB.PrjPcb |  |  | Contact:
 | Project: | PiRA-RTC-HAT-PCB.PrjPcb
 | Variant: | None |  |  |  |  |  |  | IRNAS
 | Report Date: | 11/06/2017 | 12:00:07 PM |  |  |  |  |  | www.irnas.eu
 | Print Date: | 2017-11-06 | 14:51:55
# | Manufacturer Part Number 1 | Manufacturer 1 | Description | Footprint | Designator | Quantity | Supplier 1 | Supplier Part Number 1 | Supplier Order Qty 1 | Supplier Stock 1 | Supplier Unit Price 1 | Supplier Subtotal 1 | Supplier Currency 1
1 | SI7635DP-T1-GE3 | VISHAY | INFINEON - BSZ120P03NS3GATMA1 - MOSFET, P-CH, -30V, -40A, PG-TSDSON-8 | PG-TSDSON-8 | T2 | 1 | Farnell | 2646394 | 20 | 1175 | 0.79 | 15.70 | GBP
2 | RCA060310R0FKEA | VISHAY | VISHAY - RCA060310R0FKEA - RES, AUTO, THICK FILM, 10R, 1%, 0603 | RES0603 | R30 | 1 | Farnell | 2616585 | 20 | 3286 | 0.12 | 2.48 | GBP
3 | RS1J-E3/61T.. | VISHAY | VISHAY - RS1J-E3/61T.. - DIODE, FAST, 1A, 600V, SMD | SMC/DO-214AC | D4 | 1 | Farnell | 9550143 | 20 | 10105 | 0.16 | 3.28 | GBP
4 | SE30AFG-M3/6A | VISHAY | VISHAY - SE30AFG-M3/6A - RECTIFIER, ESD, 400V, 3A, DO-221AC | SODFL127P600-8N | D5 | 1 | Farnell | 2313878 | 20 | 13454 | 0.31 | 6.12 | GBP
5 | BQ24296RGET | TEXAS INSTRUMENTS | IC LI+ CHARGER PWR MGMT 24VQFN | QFN4x4 | U1 | 1 | Farnell | 2373541 | 20 | 413 | 2.02 | 40.40 | GBP
6 | TPL5110DDCT | TEXAS INSTRUMENTS | TEXAS INSTRUMENTS - TPL5110DDCT - NANO TIMER, SINGLE, 5.5V, SOT-23-6 | SOT236 | U8 | 1 | Farnell | 2471145 | 20 | 1202 | 0.70 | 14.06 | GBP
7 | TPS630701RNMT | TEXAS INSTRUMENTS | TEXAS INSTRUMENTS - TPS630701RNMT - DC/DC CONV, BUCK-BOOST, 2.4MHZ, VQFN-15 | VQFN TPS | U2 | 1 | Farnell | 2643432 | 20 | 476 | 2.17 | 43.40 | GBP
8 | MM3Z3V0T1G | ON SEMICONDUCTOR | ON SEMICONDUCTOR - MM3Z3V0T1G - ZENER DIODE, 200MW, 3V, SOD-323 | SOD-323 2L | D2 | 1 | Farnell | 2463510 | 20 | 3551 | 0.14 | 2.80 | GBP
9 | MMBT3904 | ON SEMICONDUCTOR | ON SEMICONDUCTOR/FAIRCHILD - MMBT3904 - TRANSISTOR, NPN, SOT-23 | SOT23127P600-8N | T1 | 1 | Farnell | 9846727 | 20 | 32062 | 0.14 | 2.88 | GBP
10 | 2N7002,215 | NEXPERIA | NEXPERIA - 2N7002,215 - MOSFET,N CH, 60V,0.3A,SOT23 | SOT23127P600-8N | T3 | 1 | Farnell | 1510761 | 20 | 279470 | 0.04 | 0.89 | GBP
11 | FDSD0420-H-1R5M=P3 | MURATA | MURATA - FDSD0420-H-1R5M=P3 - INDUCTOR, SHIELDED, 1.5UH, 5.1A, 20% | FDSD0402 | L1, L2 | 2 | Farnell | 2530091 | 40 | 1391 | 0.71 | 28.60 | GBP
12 | GRM188R61C475KAAJD | MURATA | MURATA - GRM188R61C475KAAJD - CAP, MLCC, X5R, 4.7UF, 16V, 0603 | CAP0603 | C2 | 1 | Farnell | 2611924 | 20 | 4366 | 0.14 | 2.86 | GBP
13 | GRM188R71C104KA01J | MURATA | MURATA - GRM188R71C104KA01J - CAP, MLCC, X7R, 0.1UF, 16V, 0603 | CAP0603 | C12, C13, C14 | 3 | Farnell | 432210 | 60 | 9766 | 0.02 | 1.07 | GBP
14 | MC0063W06031100R, MCWR06X1000FTL | MULTICOMP | MULTICOMP - MC0063W06031100R - RES, THICK FILM, 100R, 1%, 0.063W, 0603 | RES0603 | R18, R27 | 2 | Farnell | 2447227 | 40 | 130143 | 0.0032 | 0.13 | GBP
15 | MC0063W06031499K | MULTICOMP | MULTICOMP - MC0063W06031499K - RES, THICK FILM, 499K, 1%, 0.063W, 0603 | RES0603 | R26, R29 | 2 | Farnell | 1171055 | 40 | 3264 | 0.01 | 0.40 | GBP
16 | MC0603B473K500CT | MULTICOMP | MULTICOMP - MC0603B473K500CT - CAP, MLCC, X7R, 47NF, 50V, 0603 | CAP0603 | C3 | 1 | Farnell | 1759116 | 20 | 50773 | 0.02 | 0.35 | GBP
17 | MC0805X226M6R3CT | MULTICOMP | MULTICOMP - MC0805X226M6R3CT - CAP, MLCC, X5R, 22UF, 0805 | CAP0805 | C7, C8, C9, C10 | 4 | Farnell | 1759415 | 80 | 43288 | 0.10 | 7.64 | GBP
18 | MCMR06X103 JTL | MULTICOMP | MULTICOMP - MCMR06X103 JTL - RES, CERAMIC, 10K, 5%, 0.1W, 0603 | RES0603 | R5, R10, R12, R16, R20, R21, R22, R31 | 8 | Farnell | 2073356 | 160 | 10031 | 0.0037 | 0.59 | GBP
19 | MCMR06X104 JTL | MULTICOMP | MULTICOMP - MCMR06X104 JTL - RES, CERAMIC, 100K, 5%, 0.1W, 0603 | RES0603 | R17, R19 | 2 | Farnell | 2073357 | 40 | 16958 | 0.01 | 0.25 | GBP
20 | MCMR06X4702FTL | MULTICOMP | MULTICOMP - MCMR06X4702FTL - RES, CERAMIC, 47K, 1%, 0.1W, 0603 | RES0603 | R23, R25 | 2 | Farnell | 2073510 | 40 | 11239 | 0.01 | 0.33 | GBP
21 | MCMR06X471 JTL | MULTICOMP | MULTICOMP - MCMR06X471 JTL - RES, CERAMIC, 470R, 5%, 0.1W, 0603 | RES0603 | R1, R13 | 2 | Farnell | 2073513 | 40 | 1510 | 0.0043 | 0.17 | GBP
22 | MCMR06X5601FTL | MULTICOMP | MULTICOMP - MCMR06X5601FTL - RES, CERAMIC, 5K6, 1%, 0.1W, 0603 | RES0603 | R6 | 1 | Farnell | 2073537 | 20 | 2834 | 0.0049 | 0.10 | GBP
23 | MCWR06X1503FTL | MULTICOMP | MULTICOMP - MCWR06X1503FTL - RES, THICK FILM, 150KOHM, 1%, 0.1W | RES0603 | R8 | 1 | Farnell | 2447254 | 20 | 4775 | 0.0031 | 0.06 | GBP
24 | MCWR06X2200FTL | MULTICOMP | MULTICOMP - MCWR06X2200FTL - RES, THICK FILM, 220R, 1%, 0.1W, 0603 | RES0603 | R7 | 1 | Farnell | 2447298 | 20 | 130953 | 0.0019 | 0.04 | GBP
25 | MCWR06X3302FTL | MULTICOMP | MULTICOMP - MCWR06X3302FTL - RES, THICK FILM, 33K, 1%, 0.1W, 0603 | RES0603 | R15 | 1 | Farnell | 2447342 | 20 | 77040 | 0.0031 | 0.06 | GBP
26 | MCWR06X3901FTL | MULTICOMP | MULTICOMP - MCWR06X3901FTL - RES, THICK FILM, 3K9, 1%, 0.1W, 0603 | RES0603 | R4 | 1 | Farnell | 2447363 | 20 | 53145 | 0.0031 | 0.06 | GBP
27 | MCWR06X4703FTL | MULTICOMP | MULTICOMP - MCWR06X4703FTL - RES, THICK FILM, 470K, 1%, 0.1W, 0603 | RES0603 | R9 | 1 | Farnell | 2447373 | 20 | 47264 | 0.0031 | 0.06 | GBP
28 | MC0805X106K160CT | MULTICOMP | TDK - CGA4J1X5R1C106K125AC - CAP, MLCC, X5R, 10UF, 16V, 0805 | CAP0805 | C1, C4, C5, C6, C11 | 5 | Farnell | 2320856 | 100 | 131169 | 0.05 | 5.04 | GBP
29 | MCP3021A5T-E/OT | MICROCHIP | MICROCHIP - MCP3021A5T-E/OT - 10BIT ADC, I2C, 1CH, SMD, SOT-23A-5 | SOT23127P600-8N - duplicate | U4 | 1 | Farnell | 1332097 | 20 | 7151 | 0.83 | 16.70 | GBP
30 | MINISMDC150F/24-2 | LITTELFUSE | LITTELFUSE - MINISMDC150F/24-2 - POLYSWITCH, SMD, 1812, 1.5A | Chip2PinSM127P600-8N | F1 | 1 | Farnell | 1345929 | 20 | 8697 | 0.46 | 9.26 | GBP
31 | BZT52C6V2 | DIODES INC. | DIODES INC. - BZT52C6V2 - DIODE, ZENER, 6.2V, 0.5W, SOD-123 | SOD123 | D6 | 1 | Farnell | 1902438 | 20 | 4408 | 0.41 | 8.30 | GBP
32 | DMG6602SVT | DIODES INC. | DIODES INC. - DMG6602SVT - MOSFET, NP CH, , 30V, 3.4, ATSOT23 | TSOT26 | U5, U6 | 2 | Farnell | 2061522 | 40 | 4581 | 0.34 | 13.56 | GBP
33 | HSMS-C190. | BROADCOM LIMITED | BROADCOM LIMITED - HSMS-C190 - LED, RED, 10MCD, 626NM | LED0603 | D1 | 1 | Farnell | 2497356 | 20 | 4472 | 0.41 | 8.28 | GBP
34 | CR0603-J/-000ELF | BOURNS | BOURNS - CR0603-J/-000ELF - RES, THICK FILM, 0R, 5%, 0.1W, 0603 | RES0603 | R2, R3, R14, R24, R28 | 5 | Farnell | 2008343 | 100 | 43937 | 0.01 | 1.46 | GBP
 |  |  |  |  |  | 61 |  |  | 1220 |  |  | 237.388
Approved |  |  |  | Notes
 |  |  |  | pcs: |  | 20 |  | Total |  | 237.388 |  | GBP
 |  |  |  |  |  |  |  | Price for 1pcs |  | 11.87 |  | GBP

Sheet: Project Information
Project Full Path | C:\Users\vojislav\Documents\PiRA-RTC-HAT\PiRA-RTC-HAT-PCB\PiRA-RTC-HAT-PCB.PrjPcb
Project Filename | PiRA-RTC-HAT-PCB.PrjPcb
Variant Name | None
Data-Source Filename | PiRA-RTC-HAT-PCB.PrjPcb
Data-Source Full Path | C:\Users\vojislav\Documents\PiRA-RTC-HAT\PiRA-RTC-HAT-PCB\PiRA-RTC-HAT-PCB.PrjPcb
Title | <Parameter Title not found>
Total Quantity | 64
Report Time | 12:00:07 PM
Report Date | 11/06/2017
Report Date & Tine | 11/06/2017 12:00:07 PM
Output Name | Bill of Materials production
Output Type | BOM_PartType
Output Generator Name | BOM
Output Generator Description | Bill of Materials

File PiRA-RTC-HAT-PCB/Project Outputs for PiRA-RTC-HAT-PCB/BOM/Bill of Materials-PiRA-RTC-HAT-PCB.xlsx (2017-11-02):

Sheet: Part List Report
 | Component list |  |  | PiRA RTC HAT
 | Source Data From: | PiRA-RTC-HAT-PCB.PrjPcb |  |  | Contact:
 | Project: | PiRA-RTC-HAT-PCB.PrjPcb
 | Variant: | None |  |  |  |  |  |  | Koruza
 | Report Date: | 09/27/2017 | 10:44:17 AM |  |  |  |  |  | www.koruza.net
 | Print Date: | 2017-09-27 | 11:11:14
# | Manufacturer Part Number 1 | Manufacturer 1 | Description | Footprint | Category | Quantity | Supplier 1 | Supplier Part Number 1 | Supplier Order Qty 1 | Supplier Stock 1 | Supplier Unit Price 1 | Supplier Subtotal 1 | Supplier Currency 1
1 | BQ24296RGET | TEXAS INSTRUMENTS | IC LI+ CHARGER PWR MGMT 24VQFN | QFN4x4 | Integrated Circuits (ICs) | 1 | Farnell | 2373541 | 5 | 442 | 3.03000 | 15.15000 | GBP
2 | TPS630701RNMT | TEXAS INSTRUMENTS | TEXAS INSTRUMENTS - TPS630701RNMT - DC/DC CONV, BUCK-BOOST, 2.4MHZ, VQFN-15 | VQFN TPS |  | 1 | Farnell | 2643432 | 5 | 578 | 2.23000 | 11.15000 | GBP
3 | CGA4J1X5R1C106K125AC | TDK | TDK - CGA4J1X5R1C106K125AC - CAP, MLCC, X5R, 10UF, 16V, 0805 | CAP0805 |  | 5 | Farnell | 2320856 | 25 | 9191 | 0.09160 | 2.29000 | GBP
4 | MMBT3904 | ON SEMICONDUCTOR/FAIRCHILD | ON SEMICONDUCTOR/FAIRCHILD - MMBT3904 - TRANSISTOR, NPN, SOT-23 | SOT23127P600-8N |  | 1 | Farnell | 9846727 | 5 | 51500 | 0.12100 | 0.60500 | GBP
5 | MM3Z3V0T1G | ON SEMICONDUCTOR | ON SEMICONDUCTOR - MM3Z3V0T1G - ZENER DIODE, 200MW, 3V, SOD-323 | SOD-323 2L |  | 1 | Farnell | 2463510 | 5 | 6591 | 0.12600 | 0.63000 | GBP
6 | 2N7002,215 | NEXPERIA | NEXPERIA - 2N7002,215 - MOSFET,N CH, 60V,0.3A,SOT23 | SOT23127P600-8N |  | 1 | Farnell | 1510761 | 5 | 327768 | 0.14500 | 0.72500 | GBP
7 | FDSD0420-H-1R5M=P3 | MURATA | MURATA - FDSD0420-H-1R5M=P3 - INDUCTOR, SHIELDED, 1.5UH, 5.1A, 20% | FDSD0402 |  | 2 | Farnell | 2530091 | 10 | 1471 | 0.71500 | 7.15000 | GBP
8 | GRM188R61C475KAAJD | MURATA | MURATA - GRM188R61C475KAAJD - CAP, MLCC, X5R, 4.7UF, 16V, 0603 | CAP0603 |  | 1 | Farnell | 2611924 | 5 | 5858 | 0.14300 | 0.71500 | GBP
9 | GRM188R71C104KA01J | MURATA | MURATA - GRM188R71C104KA01J - CAP, MLCC, X7R, 0.1UF, 16V, 0603 | CAP0603 |  | 2 | Farnell | 2688519 | 10 | 1363 | 0.01780 | 0.17800 | GBP
10 | MC0063W06031100R | MULTICOMP | MULTICOMP - MC0063W06031100R - RES, THICK FILM, 100R, 1%, 0.063W, 0603 | RES0603 |  | 2 | Farnell | 2447227 | 10 | 228551 | 0.03200 | 0.32000 | GBP
11 | MC0603B473K500CT | MULTICOMP | MULTICOMP - MC0603B473K500CT - CAP, MLCC, X7R, 47NF, 50V, 0603 | CAP0603 |  | 1 | Farnell | 1759116 | 5 | 46043 | 0.01760 | 0.08800 | GBP
12 | MC0805X226M6R3CT | MULTICOMP | MULTICOMP - MC0805X226M6R3CT - CAP, MLCC, X5R, 22UF, 0805 | CAP0805 |  | 4 | Farnell | 1759415 | 20 | 73771 | 0.21700 | 4.34000 | GBP
13 | MCMR06X103 JTL | MULTICOMP | MULTICOMP - MCMR06X103 JTL - RES, CERAMIC, 10K, 5%, 0.1W, 0603 | RES0603 |  | 11 | Farnell | 2073356 | 55 | 9491 | 0.00610 | 0.33550 | GBP
14 | MCMR06X104 JTL | MULTICOMP | MULTICOMP - MCMR06X104 JTL - RES, CERAMIC, 100K, 5%, 0.1W, 0603 | RES0603 |  | 2 | Farnell | 2073357 | 10 | 2327 | 0.00620 | 0.06200 | GBP
15 | MCMR06X471 JTL | MULTICOMP | MULTICOMP - MCMR06X471 JTL - RES, CERAMIC, 470R, 5%, 0.1W, 0603 | RES0603 |  | 3 | Farnell | 2073513 | 15 | 2686 | 0.00430 | 0.06450 | GBP
16 | MCMR06X5601FTL | MULTICOMP | MULTICOMP - MCMR06X5601FTL - RES, CERAMIC, 5K6, 1%, 0.1W, 0603 | RES0603 |  | 1 | Farnell | 2073537 | 5 | 8725 | 0.00490 | 0.02450 | GBP
17 | MCWR06X1503FTL | MULTICOMP | MULTICOMP - MCWR06X1503FTL - RES, THICK FILM, 150KOHM, 1%, 0.1W | RES0603 |  | 1 | Farnell | 2447254 | 5 | 11345 | 0.00310 | 0.01550 | GBP
18 | MCWR06X2200FTL | MULTICOMP | MULTICOMP - MCWR06X2200FTL - RES, THICK FILM, 220R, 1%, 0.1W, 0603 | RES0603 |  | 1 | Farnell | 2447298 | 5 | 99015 | 0.00190 | 0.00950 | GBP
19 | MCWR06X3302FTL | MULTICOMP | MULTICOMP - MCWR06X3302FTL - RES, THICK FILM, 33K, 1%, 0.1W, 0603 | RES0603 |  | 1 | Farnell | 2447342 | 5 | 69838 | 0.00310 | 0.01550 | GBP
20 | MCWR06X3901FTL | MULTICOMP | MULTICOMP - MCWR06X3901FTL - RES, THICK FILM, 3K9, 1%, 0.1W, 0603 | RES0603 |  | 1 | Farnell | 2447363 | 5 | 14847 | 0.00310 | 0.01550 | GBP
21 | MCWR06X4703FTL | MULTICOMP | MULTICOMP - MCWR06X4703FTL - RES, THICK FILM, 470K, 1%, 0.1W, 0603 | RES0603 |  | 1 | Farnell | 2447373 | 5 | 30272 | 0.00310 | 0.01550 | GBP
22 | MCP3021A5T-E/OT | MICROCHIP | MICROCHIP - MCP3021A5T-E/OT - 10BIT ADC, I2C, 1CH, SMD, SOT-23A-5 | SOT23127P600-8N - duplicate |  | 1 | Farnell | 1332097 | 5 | 8474 | 0.92600 | 4.63000 | GBP
23 | DS3231M+TRL | MAXIM INTEGRATED PRODUCTS | MAXIM INTEGRATED PRODUCTS - DS3231M+TRL - RTC, I2C, WSOIC-16 | SOIC127P1030X265-16N |  | 1 | Farnell | 2515485 | 5 | 838 | 6.41000 | 32.05000 | GBP
24 | BSZ120P03NS3GATMA1 | INFINEON | INFINEON - BSZ120P03NS3GATMA1 - MOSFET, P-CH, -30V, -40A, PG-TSDSON-8 | PG-TSDSON-8 |  | 1 | Farnell | 2617428 | 5 | 3706 | 0.56300 | 2.81500 | GBP
25 | HSMS-C190. | BROADCOM LIMITED | BROADCOM LIMITED - HSMS-C190 - LED, RED, 10MCD, 626NM | LED0603 |  | 2 | Farnell | 2497356 | 10 | 543 | 0.33600 | 3.36000 | GBP
26 | CR0603-J/-000ELF | BOURNS | BOURNS - CR0603-J/-000ELF - RES, THICK FILM, 0R, 5%, 0.1W, 0603 | RES0603 |  | 3 | Farnell | 2008343 | 15 | 3954 | 0.01460 | 0.21900 | GBP
 |  |  |  |  |  | 52 |  |  | 260 |  |  | 86.973
Approved |  |  |  | Notes
 |  |  |  |  |  | 5 | pcs: | Total |  | 86.973 |  | GBP
 |  |  |  |  |  |  |  | Price for 1pcs |  | 17.39 |  | GBP

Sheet: Project Information
Project Full Path | C:\Users\vojislav\Documents\PiRA-RTC-HAT\PiRA-RTC-HAT-PCB\PiRA-RTC-HAT-PCB.PrjPcb
Project Filename | PiRA-RTC-HAT-PCB.PrjPcb
Variant Name | None
Data-Source Filename | PiRA-RTC-HAT-PCB.PrjPcb
Data-Source Full Path | C:\Users\vojislav\Documents\PiRA-RTC-HAT\PiRA-RTC-HAT-PCB\PiRA-RTC-HAT-PCB.PrjPcb
Title | <Parameter Title not found>
Total Quantity | 52
Report Time | 10:44:17 AM
Report Date | 09/27/2017
Report Date & Tine | 09/27/2017 10:44:17 AM
Output Name | Bill of Materials
Output Type | BOM_PartType
Output Generator Name | BOM
Output Generator Description | Bill of Materials

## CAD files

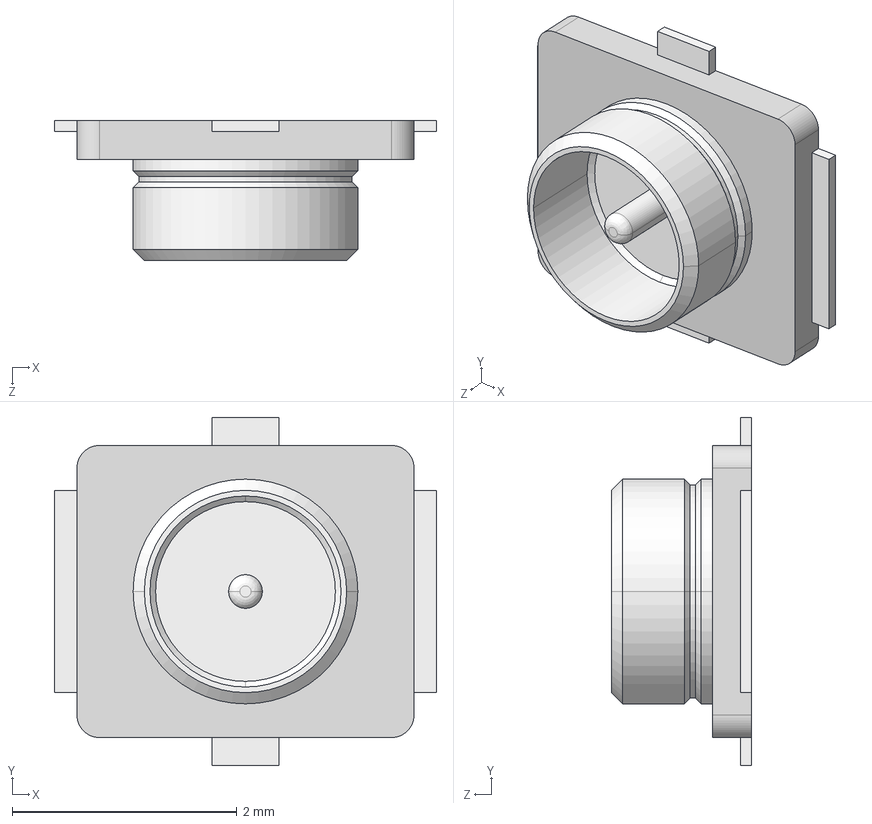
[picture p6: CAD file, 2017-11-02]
PiRA-RTC-HAT-PCB/step/SW3dPS-UFL-R-SMD.STEP
3.40 x 3.10 x 1.25 mm
SW3dPS-UFL-R-SMD_Part_525
SW3dPS-UFL-R-SMD_Part_540
SW3dPS-UFL-R-SMD_Part_739
SW3dPS-UFL-R-SMD_Part_555
SW3dPS-UFL-R-SMD_Part_578
SW3dPS-UFL-R-SMD_Part_562

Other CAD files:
PiRA-RTC-HAT-PCB/PiRA-RTC-HAT-PCB.DWG

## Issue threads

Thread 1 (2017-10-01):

Current and voltage measurement - battery indicator

VojislavM, 2017-10-01:
See all fearures of ina219 sensor

VojislavM, 2017-10-02:
https://hackaday.com/2017/09/29/oled-hacked-power-bank/#more-274878

VojislavM, 2017-10-09:
INA219 is too expensive for this project.

Closed 2017-10-09.

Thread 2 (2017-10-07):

Charger not working, fault condition

SloMusti, 2017-10-07:
The bq24296 charger LED is blinking with 1Hz and reports a fault. Charger is not working. Evaluating the conditions that could lead to this:

The REGN is enabled when all the conditions are valid.
1. VBUS above VVBUS_UVLOZ  (3.6V) - measured 5.1V
2. VBUS above VBAT+ VSLEEPZ in buck mode or VBUS below VBAT+ VSLEEPin boost mode. Vbat 3.2V, correct.
3. After typical 220-ms delay (100 ms minimum) is complete

If one of the above conditions is not valid, the device is in high impedance mode (HIZ) with REGN LDO off.

Given this is not the cause, there must be some correlation to HIZ mode. PG is low, so input voltage check is completed. TS circuit is checked and operates as expected.

Checking I2C registers for faults:

USB disconnected:
```
pi@ ~ $ i2cdump -r 0x00-0x0a 1 0x6b
     0  1  2  3  4  5  6  7  8  9  a  b  c  d  e  f    0123456789abcdef
00: 37 1b 60 11 b2 9c 73 4b 00 80 20                   7?`???sK.?
```

USB connected:
```
pi@ ~ $ i2cdump -r 0x00-0x0a 1 0x6b
     0  1  2  3  4  5  6  7  8  9  a  b  c  d  e  f    0123456789abcdef
00: 37 1b 60 11 b2 9c 73 4b 85 81 20                   7?`???sK??
```

SloMusti, 2017-10-07:
Timer and NTC faults are indicated. REGN must work for NTC fault to be cleared, so that can not happen.

VojislavM, 2017-11-02:
bad soldering problem

Closed 2017-11-02.

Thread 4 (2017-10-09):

MicroUSB port hardware footprint

SloMusti, 2017-10-09:
MicroUSB hardware footprint is missing two small holes for plastic pins that center the connector.

VojislavM, 2017-10-09:
Copy the footprint from Koruza CM board

VojislavM, 2017-11-17:
footprint changed in the library

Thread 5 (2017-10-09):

Wrong footrping in BOM for T2

SloMusti, 2017-10-09:
T2 component in BOM has wrong footprint and thus the part could not be soldered. It has been temporarily replaced by SI7335DP-t1-ge3

VojislavM, 2017-11-17:
component replaced in the schematic. BOM will now have right component

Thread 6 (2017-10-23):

Wrong inscription for charging status LED

bbratus, 2017-10-23:
Inscription "charging statsu" instead of "charging status" for D1,

Closed 2017-10-31.

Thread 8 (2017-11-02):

Timer DOne pull down

VojislavM, 2017-11-02:
Pin Done form the timer needs the pull down because of the rpi gpio pin. 10k

VojislavM, 2017-11-17:
done in the sch

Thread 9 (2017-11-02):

signal diodes for gpio

VojislavM, 2017-11-02:
Add serial zener diodes to the signals:
* RTC_EN_5V
* TIMER_EN_5V
because the pinput voltage is high for the rpi

VojislavM, 2017-11-03:
possible solution is also a series resistor.

VojislavM, 2017-11-17:
added serial resistors in the sch 470k R32 i R33

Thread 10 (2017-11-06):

under voltage protection

VojislavM, 2017-11-06:
add resistor divider for under voltage protection on FET

VojislavM, 2017-11-17:
added resistor devider: R34 1M2 and R9 470k + C15

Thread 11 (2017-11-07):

fine tune charge current

VojislavM, 2017-11-07:
T1

SloMusti, 2017-11-07:
Current configuration regulates the input voltage with the current limit to 4.3V. At 4.5V of input voltage charging current is 1.7A.

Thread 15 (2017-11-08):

add resistors

VojislavM, 2017-11-08:
TIMER_DONE - Pull down 10k
TIMER_EN_5V serial 470k
RTC_EN_5V serial 470k
serail inline ENABLE_5V

VojislavM, 2017-11-08:
this will be implemented in the version v0.3, and soldered on tracks in current version v0.2

VojislavM, 2017-11-17:
done in sch

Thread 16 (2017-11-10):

Add jumper to select Vbat and 5V on Mosfet out

SloMusti, 2017-11-10:
Add jumper to select Vbat and 5V on Mosfet out, so either can be switched.

VojislavM, 2017-11-17:
added to the sch

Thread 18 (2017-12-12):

version v1.0 MCU

VojislavM, 2017-12-12:
## Features
 * single cell LiPo cell charging of up to 3A (multiple 18650 cells supported) + **LifePo4 supprot**
 * solar panel charging (Voltaic systems 6W panels in parallel recommended)
 * USB charging, compatible with QI wireless chargers
 * advanced current limiting, to support wide array of chargers
 * precise charging control via i2c (BQ24296)
 * battery temperature protection with thermistor
 * battery reverse polarity protection and fuse (3A)
 * high-current battery output mosfet (for 3G or satellite modems)
 * LORA RMF95 communication module
 * battery voltage precise measurement (MCP3021)

 * advancerd power scheduling for robust applications:
   * power timer TPL5110 for configurable scheduled boot 1s-7200s or one-time power up on charging
   * RTC DS3231 for configurable scheduled boot and timekeeping
   * configurable power-up sources
   * power-up on charging
   * power-up from power timer
   * power-up from RTC
   * power-up from self-enable (cpu signal)

**All featrues for advance power scheduling will be done with low power MCU:**
* low power
* low power timer interrupt in sleep mode
* RTC interrupt in sleep mode
* comunication with main CPU (UART/SPI/I2C)
* communication with user in standalone applications for configuration:
  * Bluetooth Low energie (BLE) or
  * USB communication
* Non-volatile memory for keeping the configuration settings.
* configurable communication with Lora (with MCU  or external CPU)

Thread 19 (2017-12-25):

assembly v0.3

VojislavM, 2017-12-25:
assembly modification:
* R34 is 1M instead of 1M2

SloMusti, 2018-01-08:
@VojislavM R39 and R40 are 10k, however that is not a suitable value and they must be removed or replaced with a much higher value.

SloMusti, 2018-01-08:
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

Diagram for resistor removal.

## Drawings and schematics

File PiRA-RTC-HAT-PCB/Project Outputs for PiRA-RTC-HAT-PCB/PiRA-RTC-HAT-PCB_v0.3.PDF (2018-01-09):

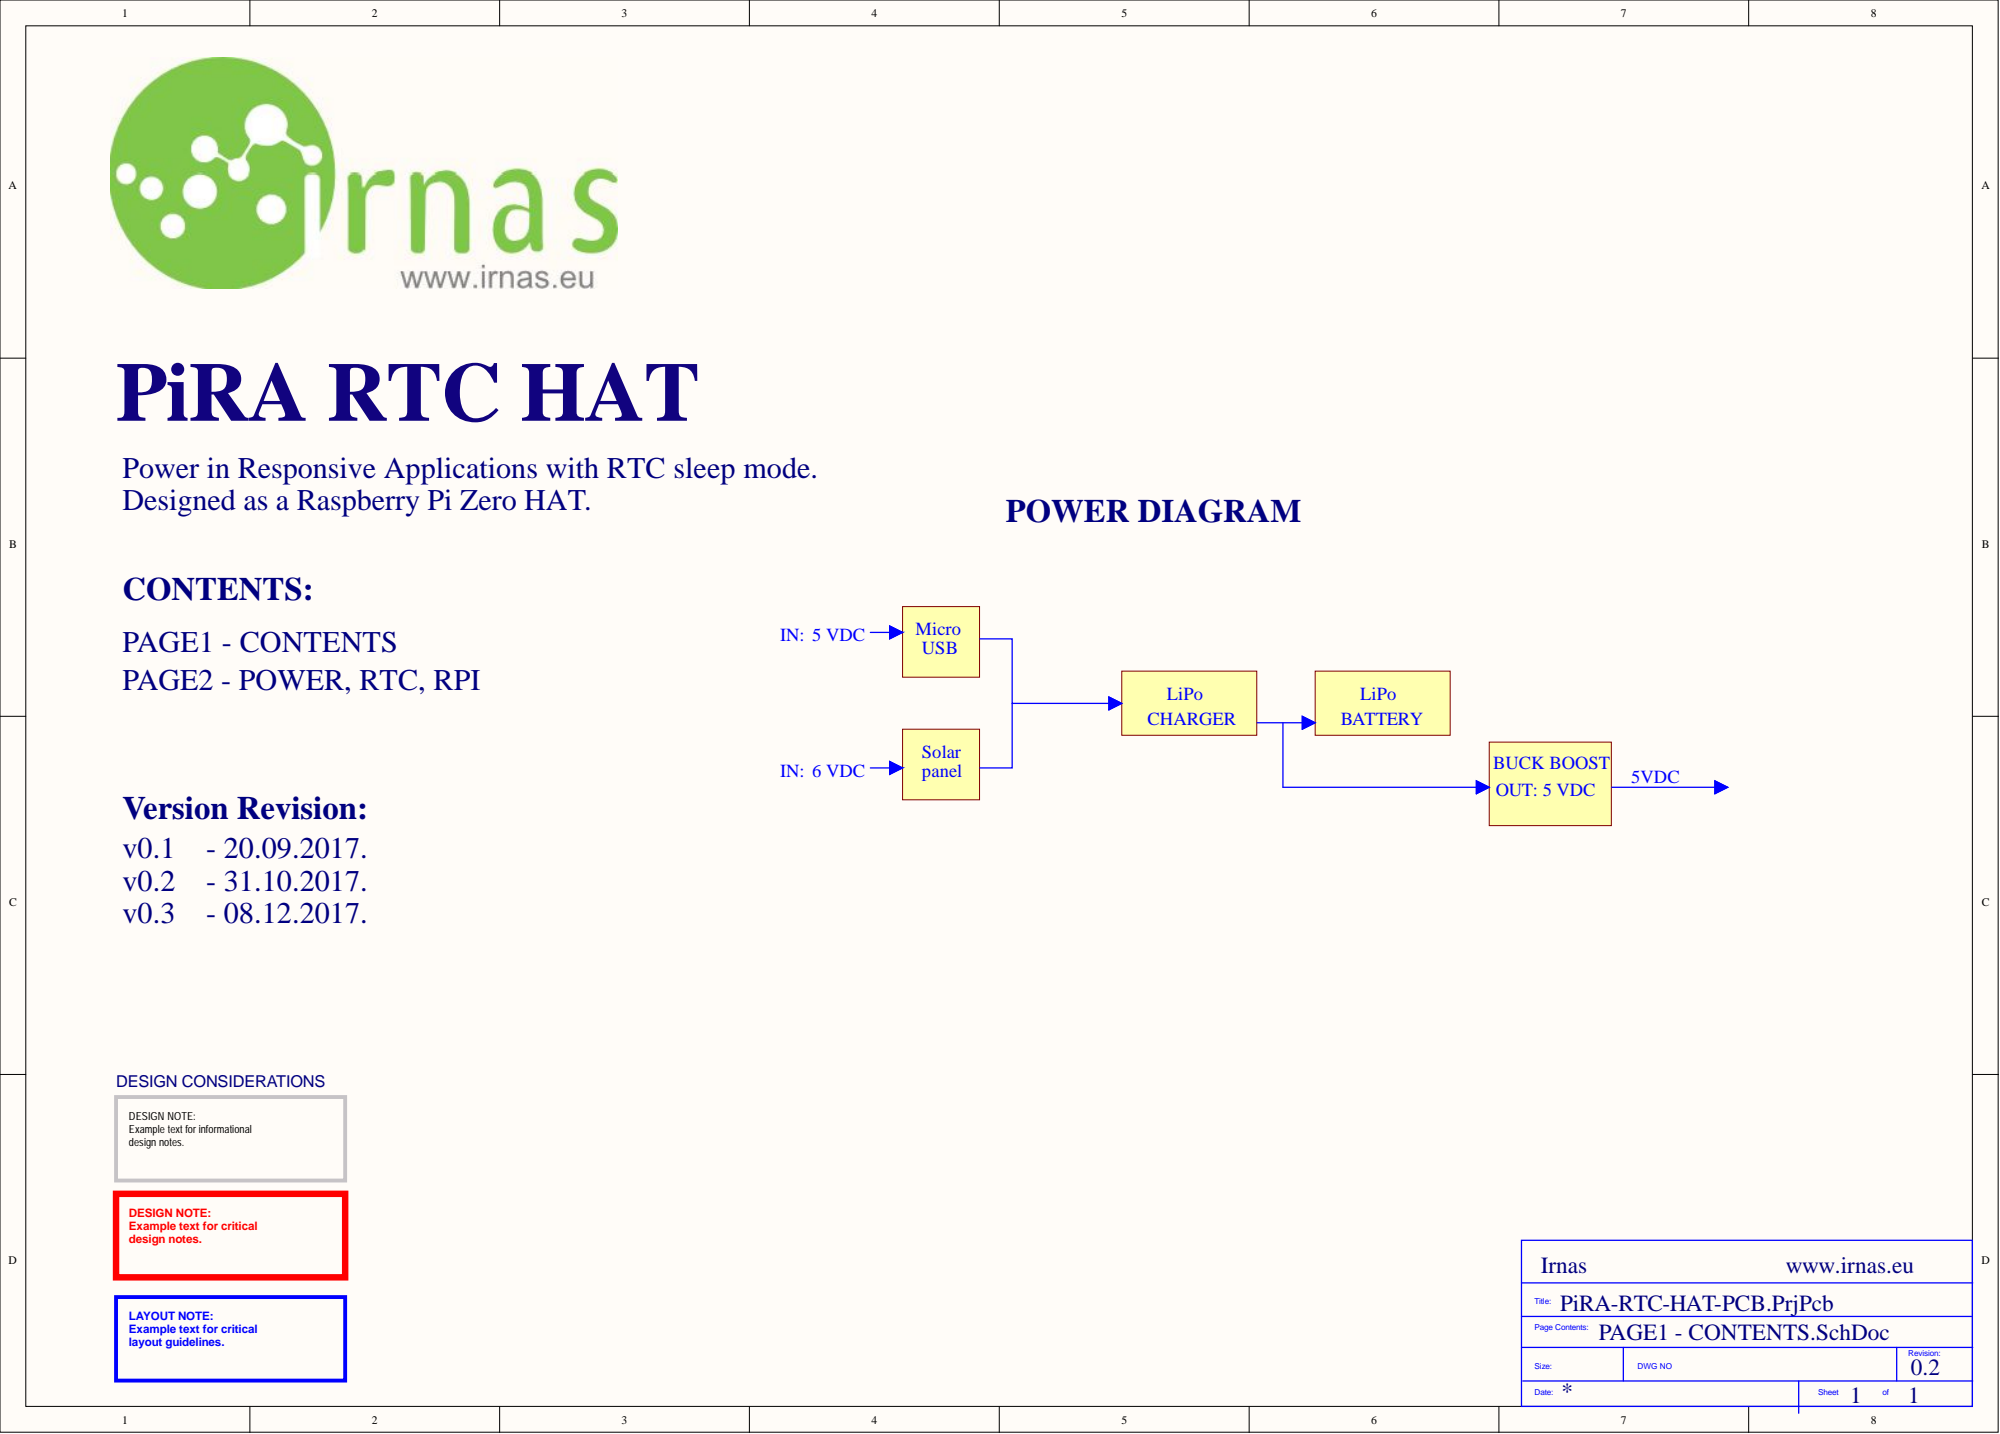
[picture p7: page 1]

Power in Responsive Applications with RTC sleep mode.
Designed as a Raspberry Pi Zero HAT.

DESIGN NOTE:
Example text for informational
design notes.

Example text for critical

PiRA-RTC-HAT-PCB.PrjPcb
PAGE1 - CONTENTS.SchDoc

LAYOUT NOTE:
layout guidelines.

Size: | DWG NO | Revision: 0.2

* Date: | 1 1 Sheet of

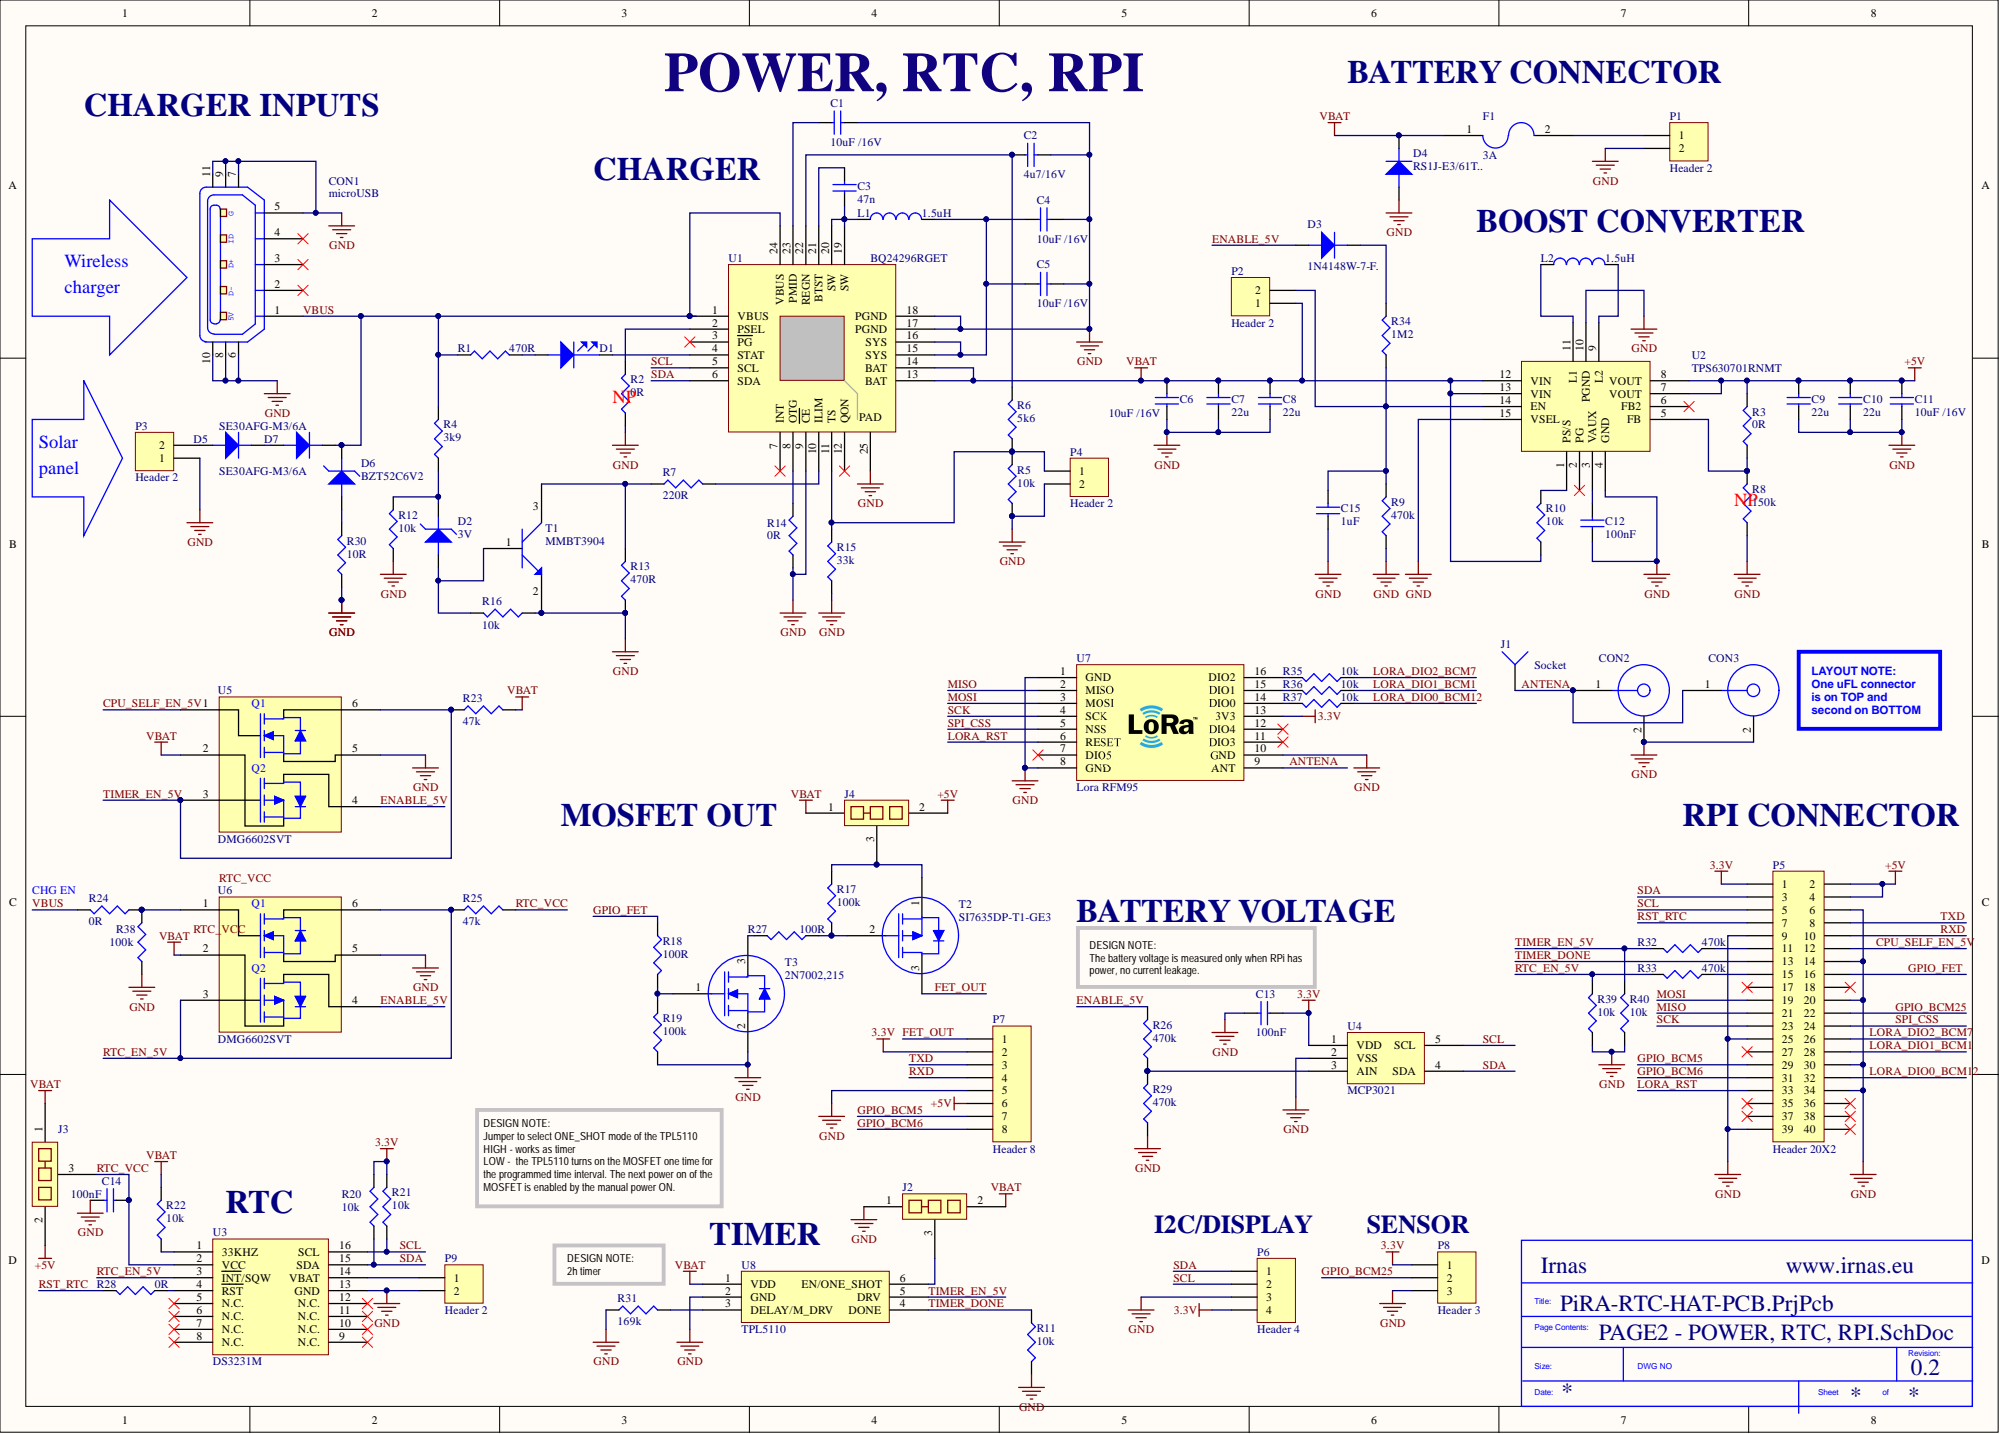
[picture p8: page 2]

SW 19 SW 20 BTST 21 REGN 22 PMID 23 VBUS 24

VIN 13
EN 14
VSEL 15

LAYOUT NOTE:
One uFL connector
is on TOP and
second on BOTTOM

MISO 2

SCK 4

DESIGN NOTE:
The battery voltage is measured only when RPi has
power, no current leakage.

Jumper to select ONE_SHOT mode of the TPL5110
HIGH - works as timer
LOW - the TPL5110 turns on the MOSFET one time for
the programmed time interval. The next power on of the
MOSFET is enabled by the manual power ON.

PiRA-RTC-HAT-PCB.PrjPcb
PAGE2 - POWER, RTC, RPI.SchDoc

Size: | DWG NO | Revision: 0.2

* Date: | * * Sheet of

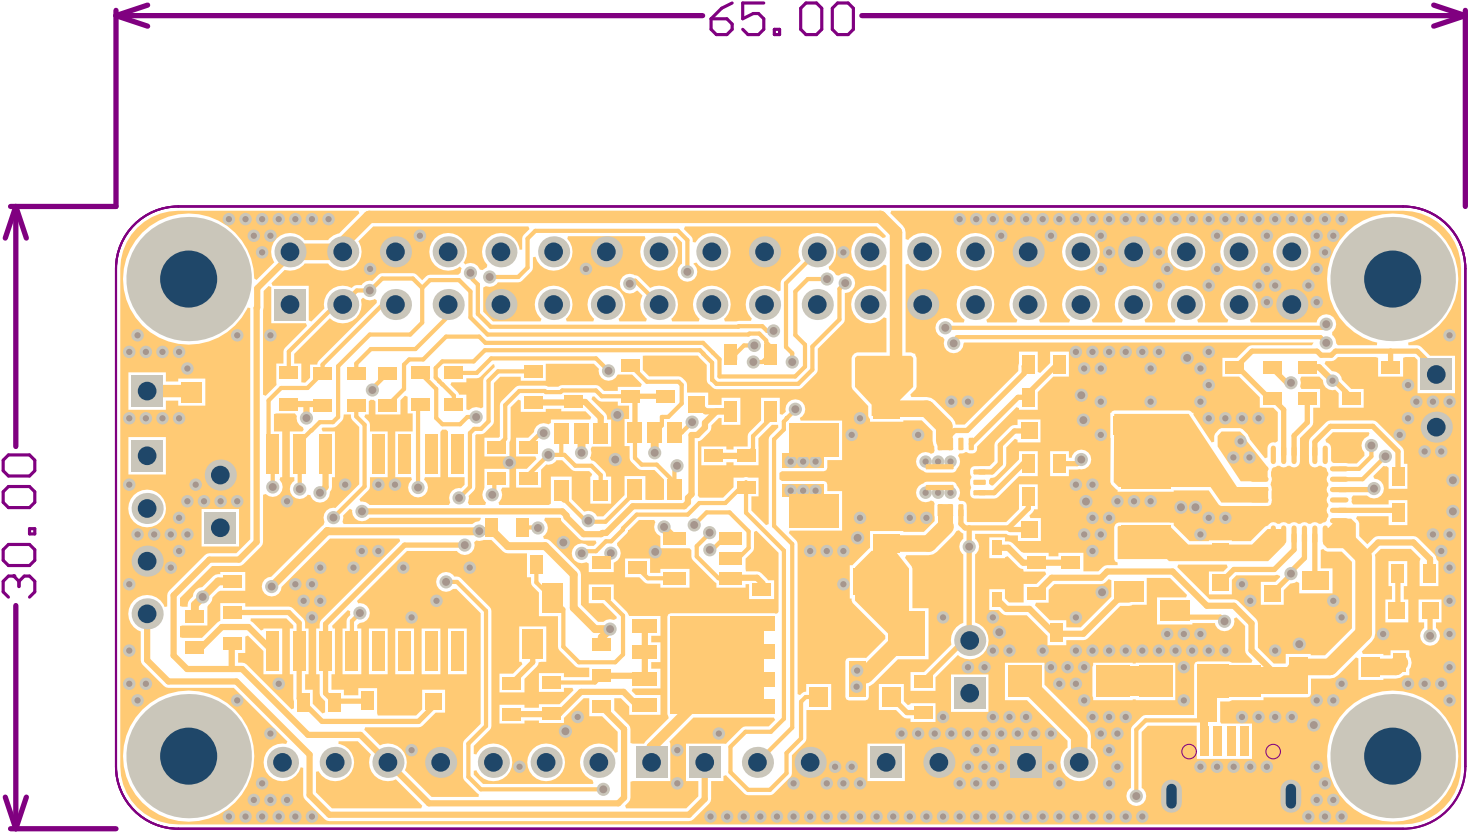
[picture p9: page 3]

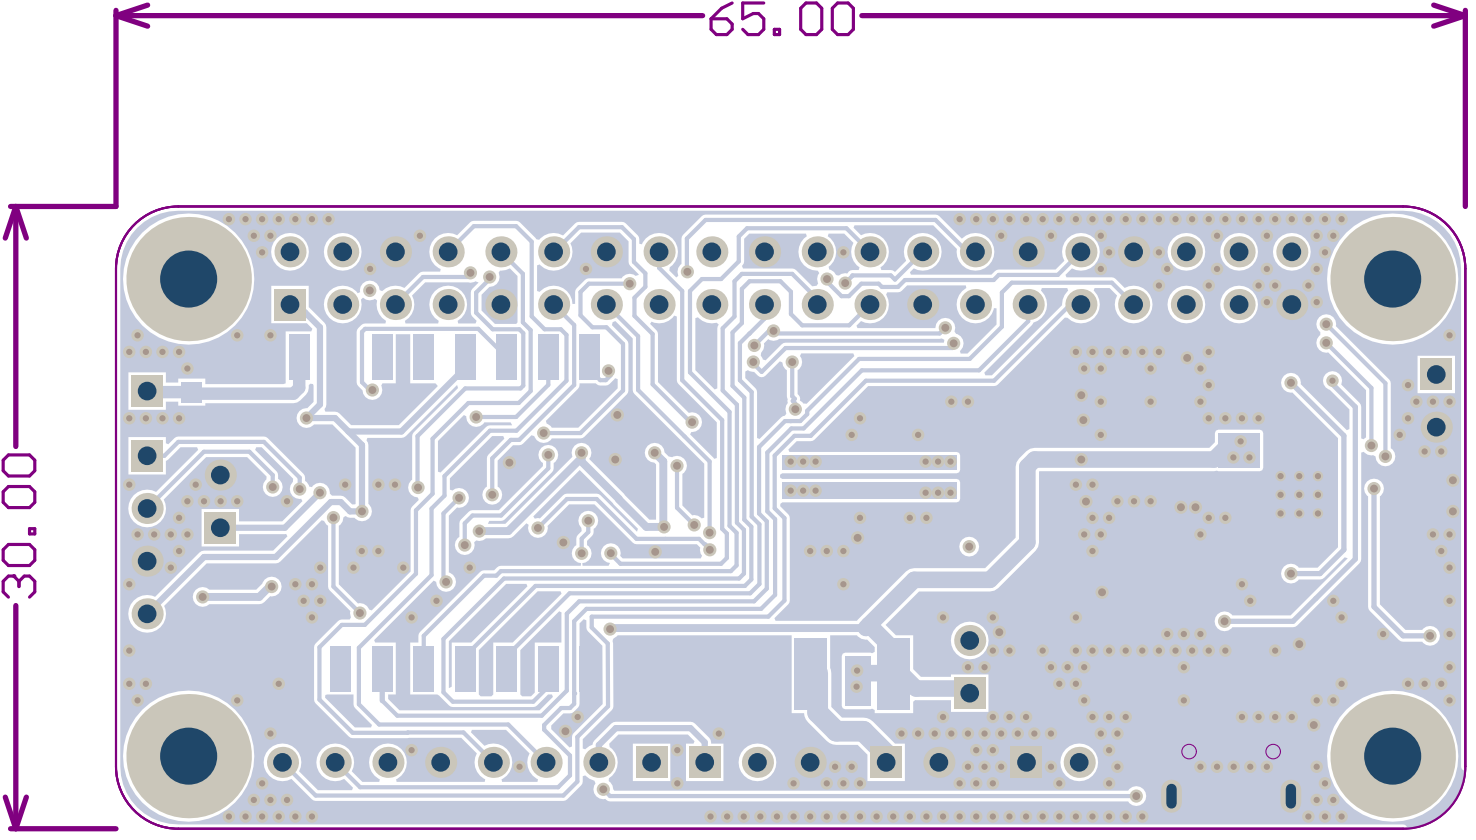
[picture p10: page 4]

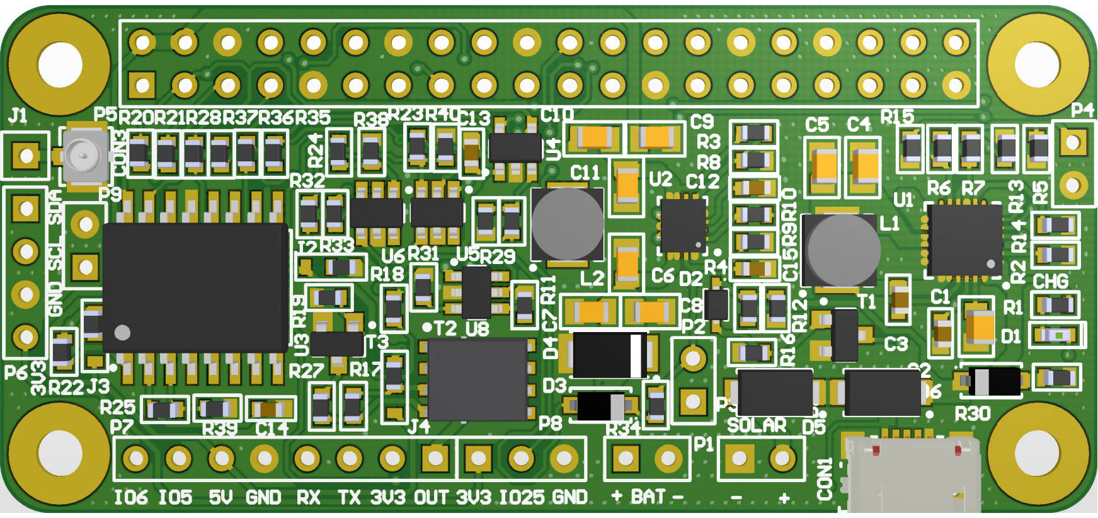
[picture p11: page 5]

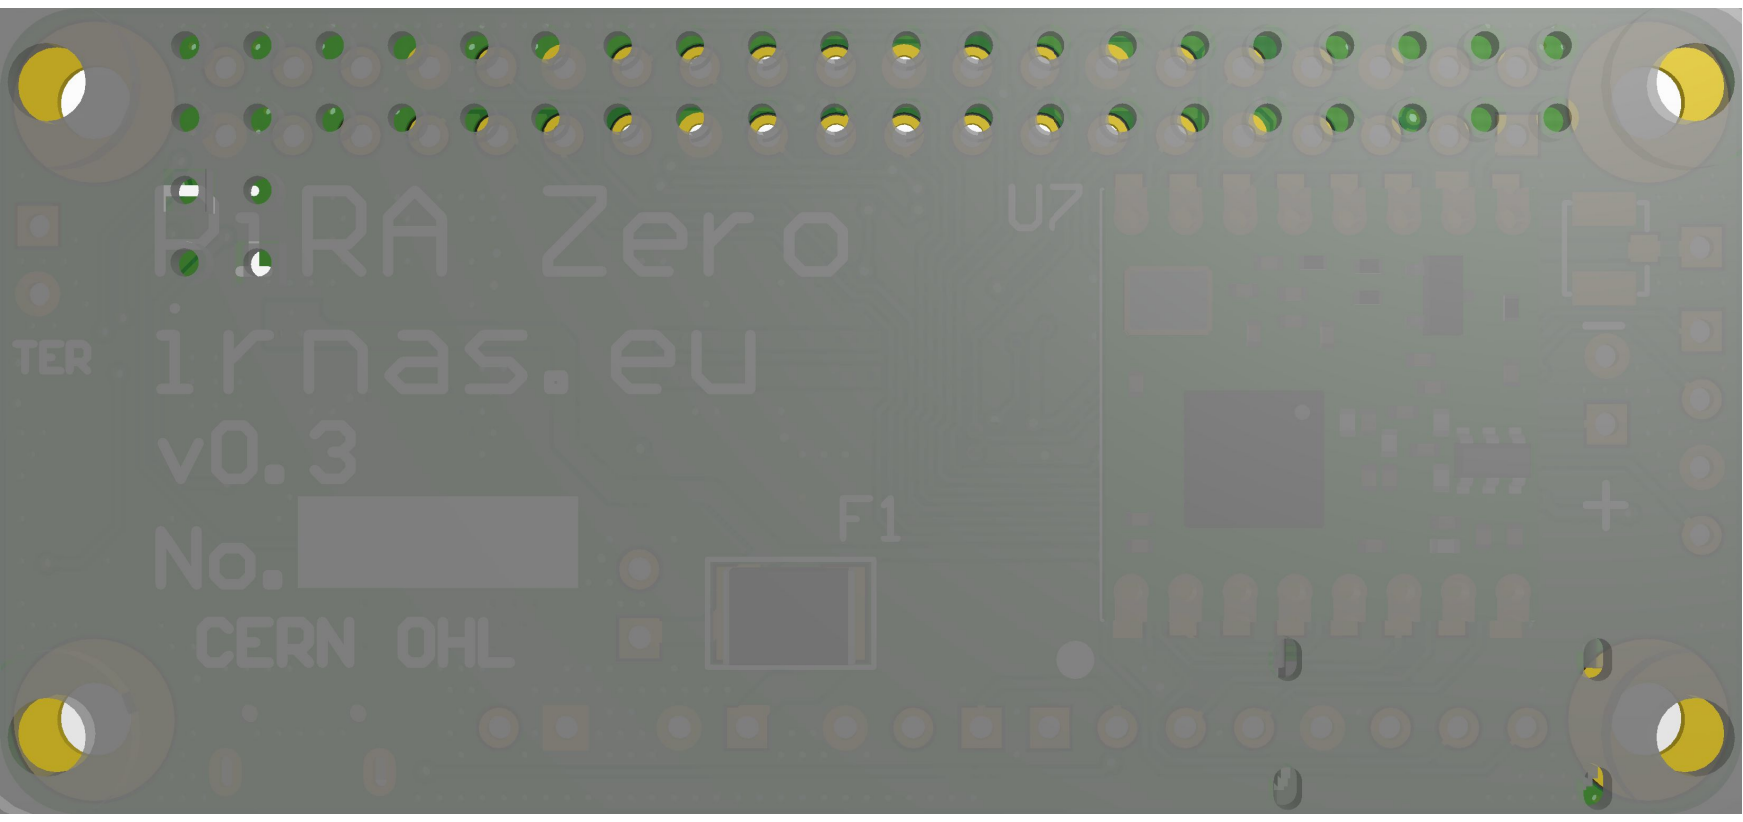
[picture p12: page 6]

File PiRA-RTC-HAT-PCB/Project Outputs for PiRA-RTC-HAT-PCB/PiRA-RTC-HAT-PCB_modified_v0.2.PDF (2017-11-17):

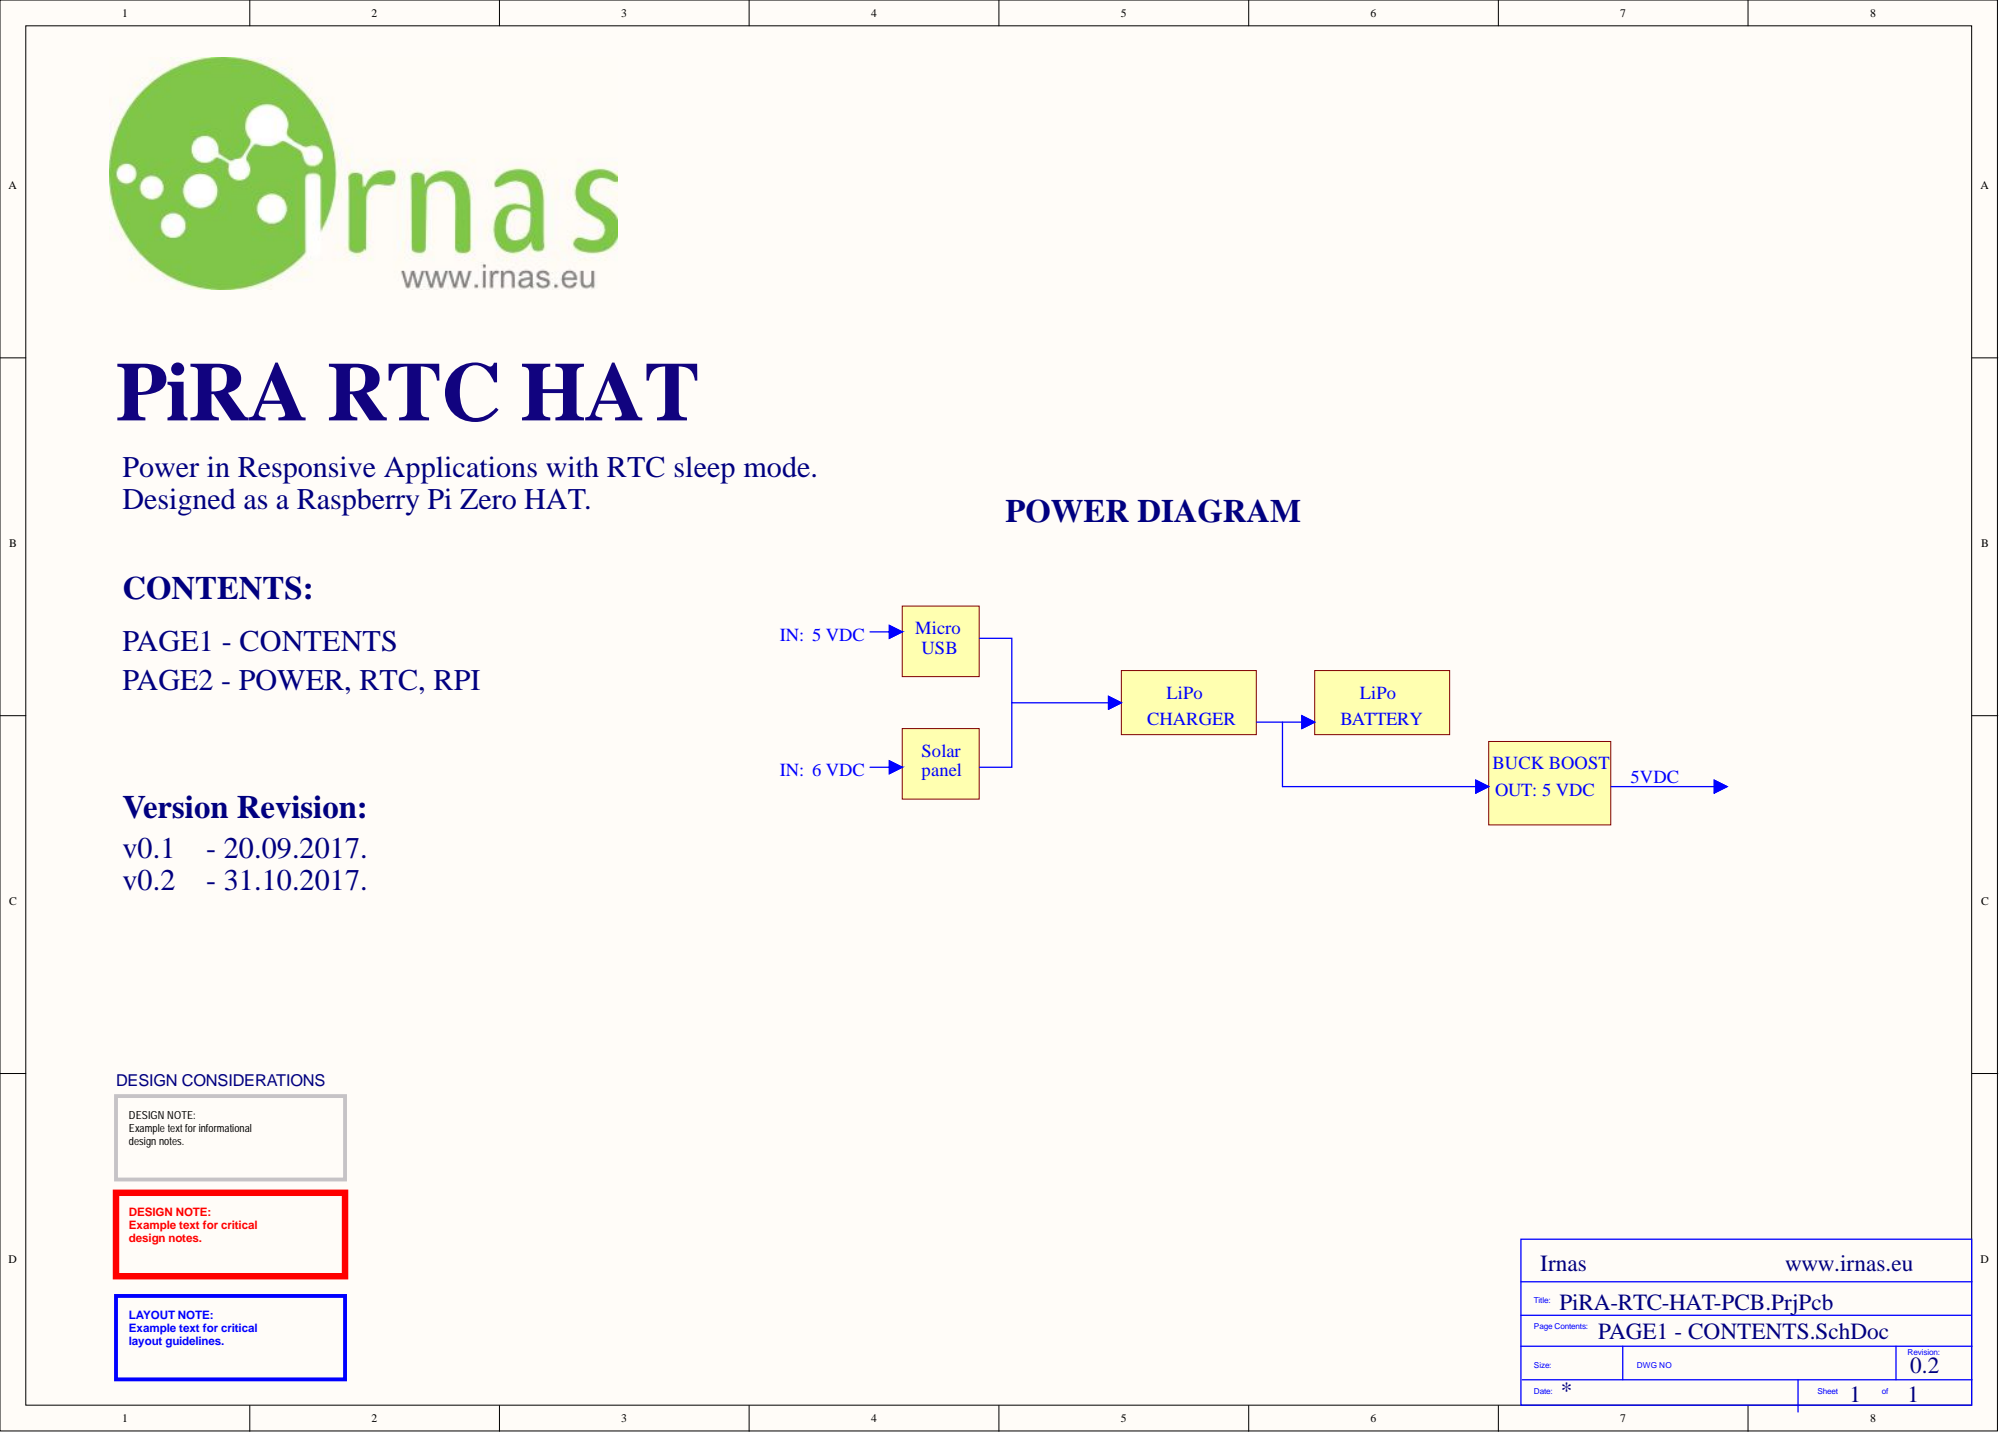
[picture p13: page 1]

Power in Responsive Applications with RTC sleep mode.
Designed as a Raspberry Pi Zero HAT.

DESIGN NOTE:
Example text for informational
design notes.

Example text for critical

PiRA-RTC-HAT-PCB.PrjPcb
PAGE1 - CONTENTS.SchDoc

LAYOUT NOTE:
layout guidelines.

Size: | DWG NO | Revision: 0.2

* Date: | 1 1 Sheet of

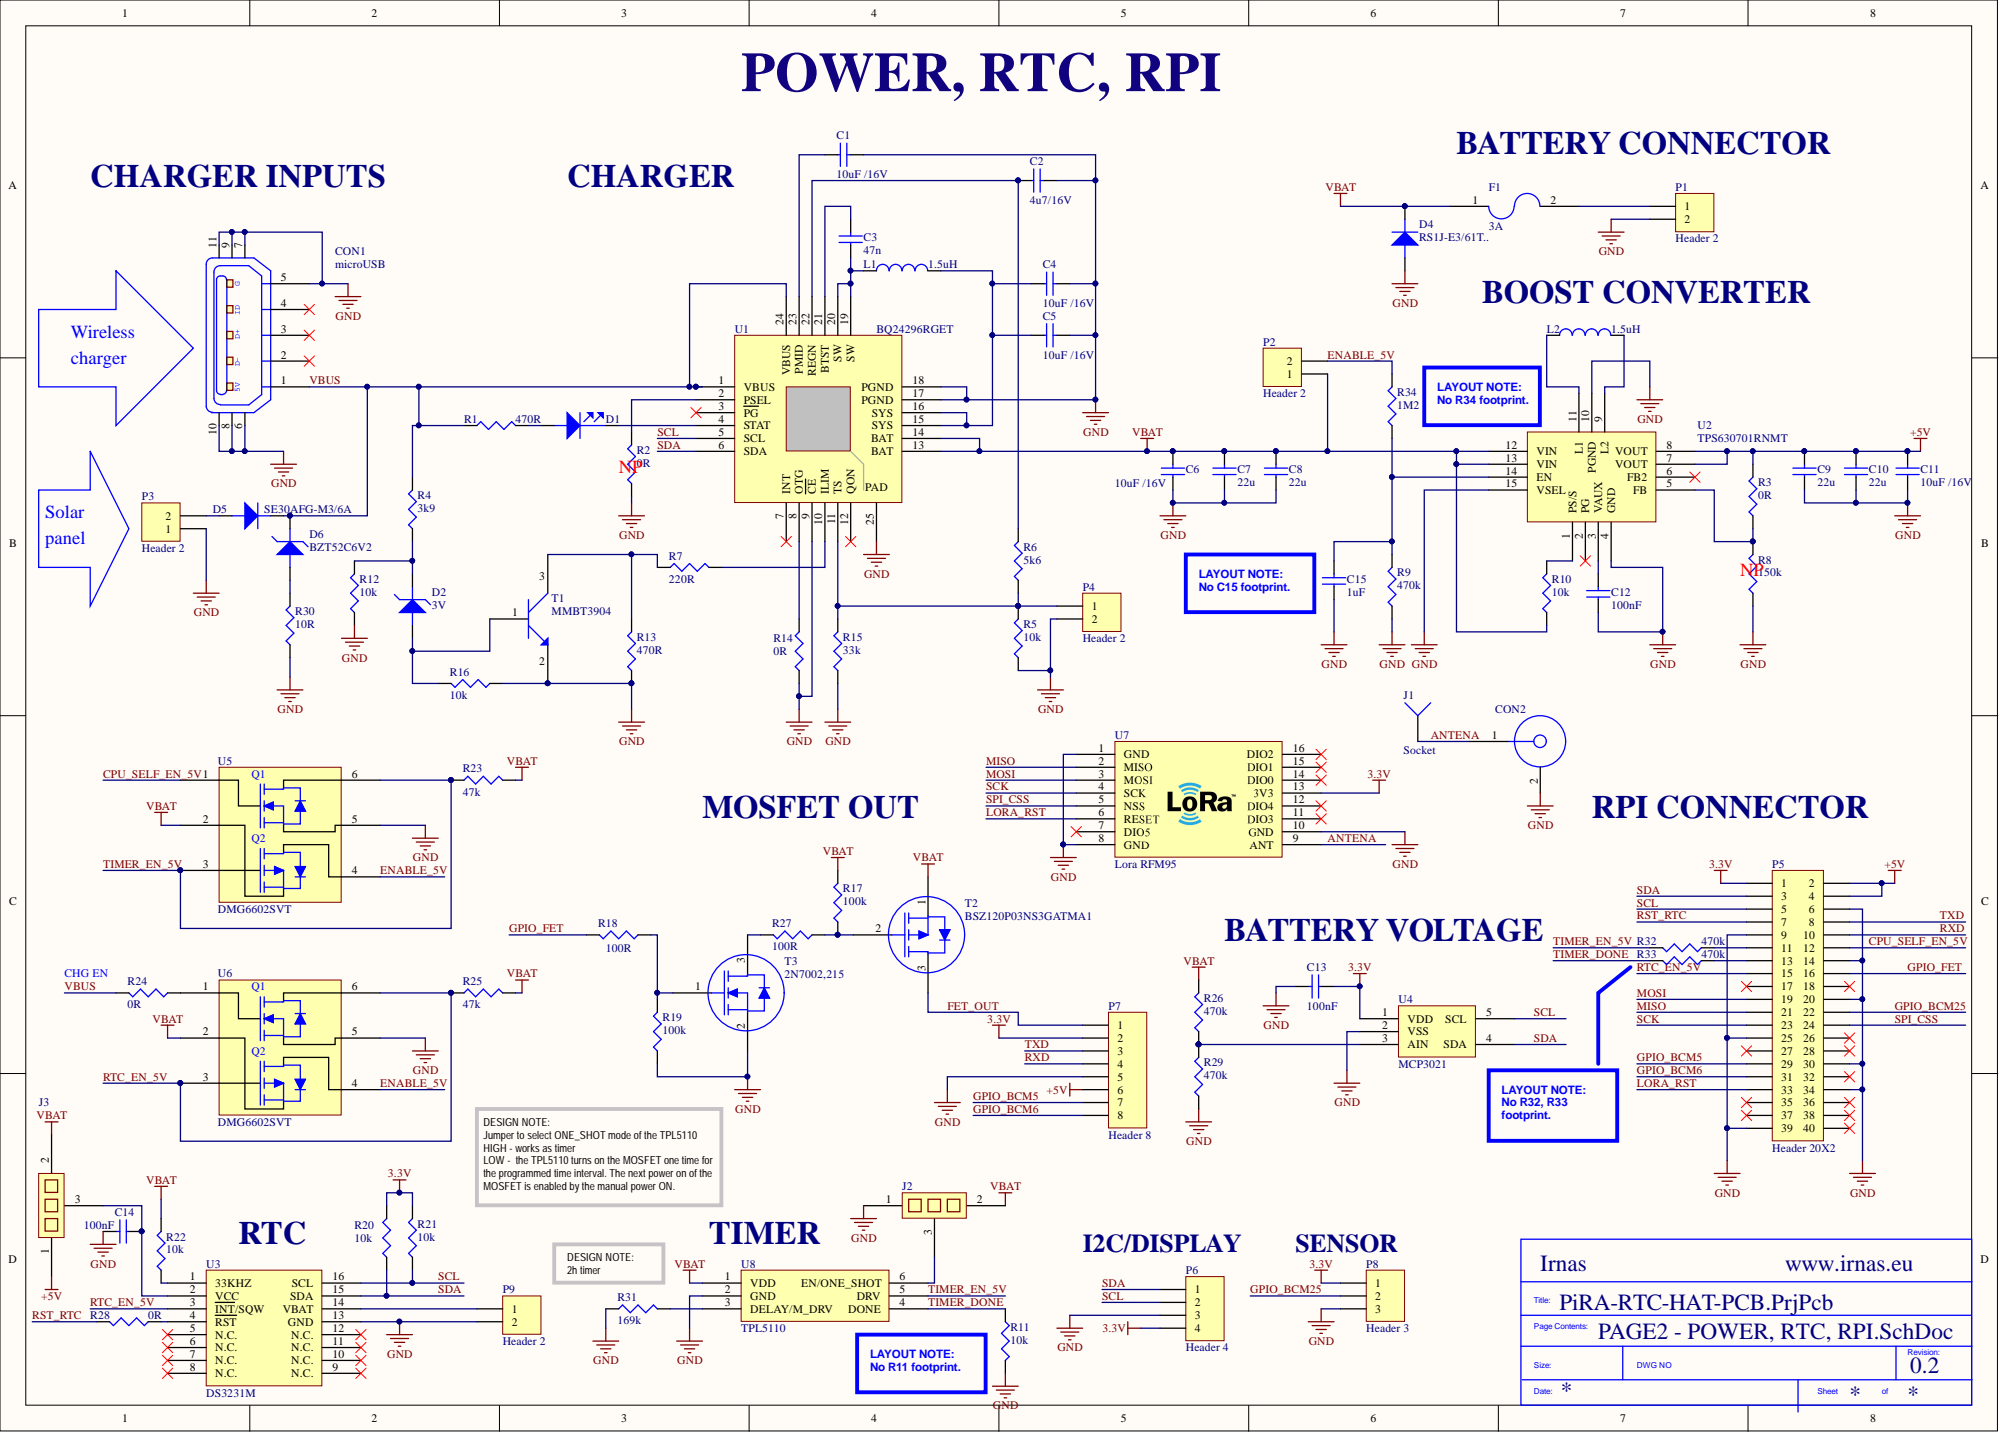
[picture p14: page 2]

SW 19 SW 20 BTST 21 REGN 22 PMID 23 VBUS 24

SCL 5

C6 | C7 | | VIN 13

VSEL 15

DESIGN NOTE:
Jumper to select ONE_SHOT mode of the TPL5110
HIGH - works as timer
LOW - the TPL5110 turns on the MOSFET one time for
the programmed time interval. The next power on of the
MOSFET is enabled by the manual power ON.

PiRA-RTC-HAT-PCB.PrjPcb
PAGE2 - POWER, RTC, RPI.SchDoc

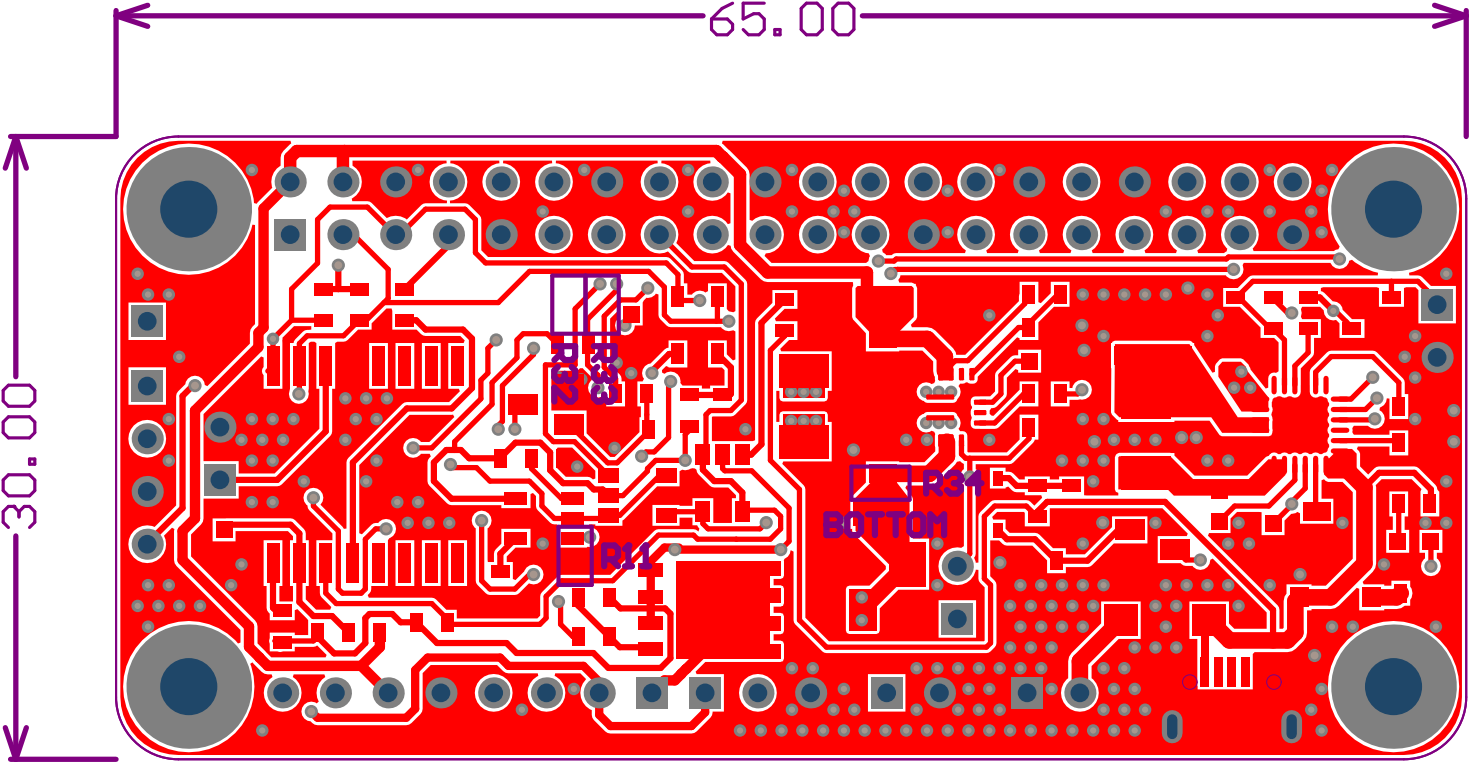
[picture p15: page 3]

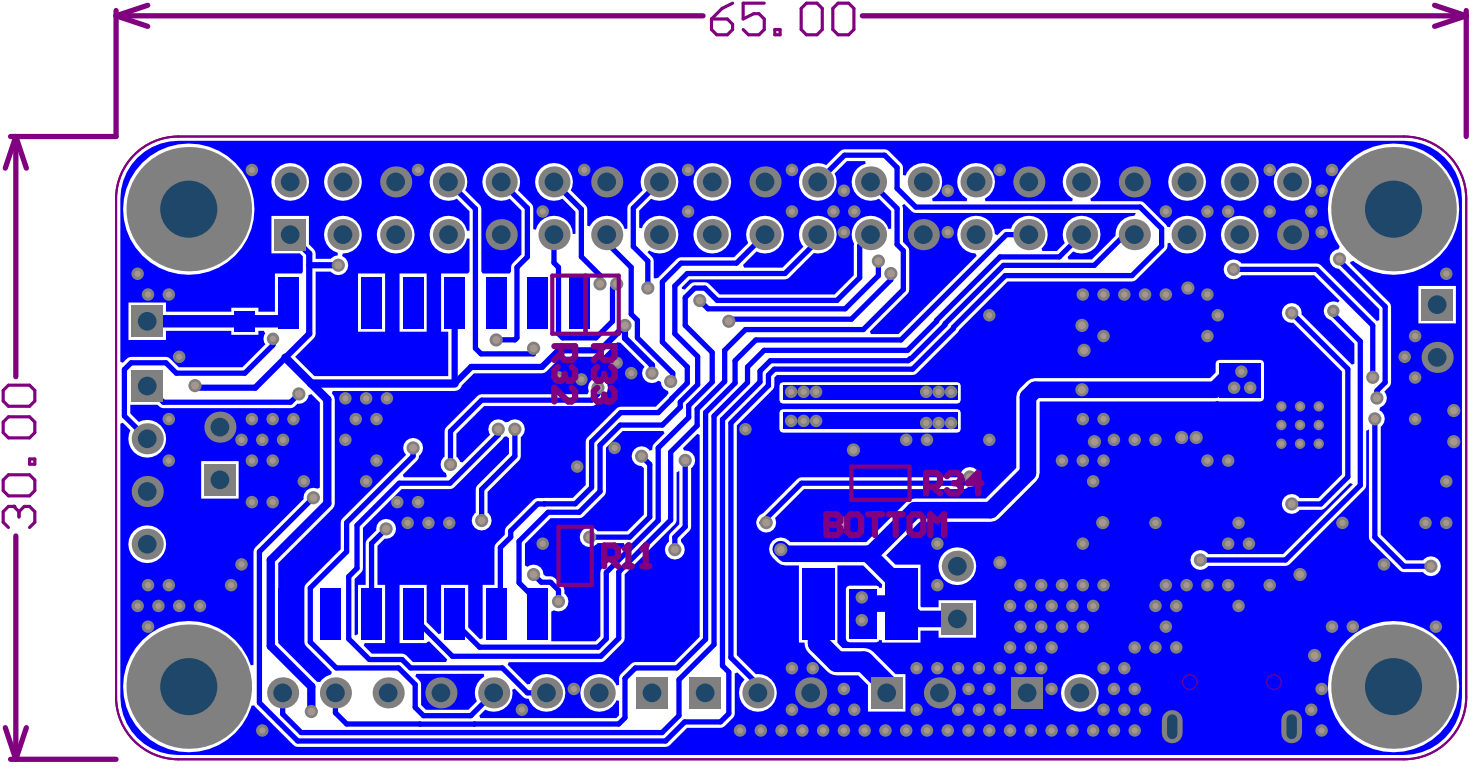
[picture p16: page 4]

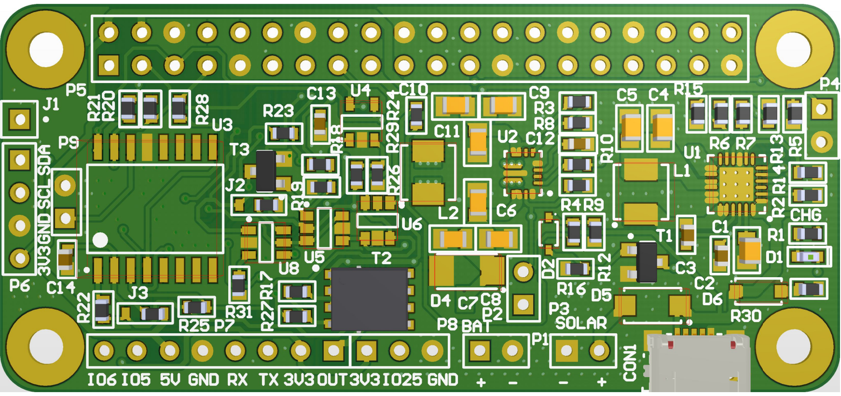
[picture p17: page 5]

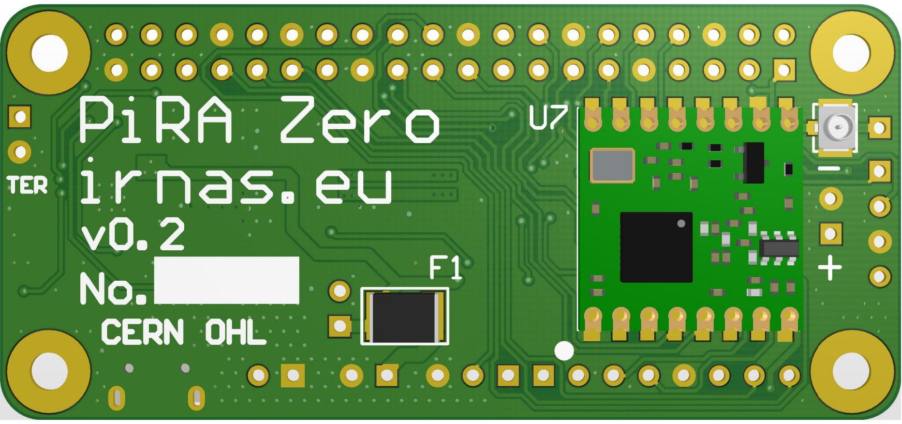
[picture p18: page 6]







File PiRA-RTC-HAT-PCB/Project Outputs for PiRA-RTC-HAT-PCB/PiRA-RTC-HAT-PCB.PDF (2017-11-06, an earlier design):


Power in Responsive Applications with RTC sleep mode.
Designed as a Raspberry Pi Zero HAT.

DESIGN NOTE:
Example text for informational
design notes.

Example text for critical

PiRA-RTC-HAT-PCB.PrjPcb
PAGE1 - CONTENTS.SchDoc

LAYOUT NOTE:
layout guidelines.

Size: | DWG NO | Revision: 0.2

* Date: | 1 1 Sheet of


18 W 19 SW 20 BTST 21 REGN 22 PMID 23 VBUS 24

QON 12 BAT 13 BAT 14 SYS 15 SYS 16 PGND 17 PGNDS

SCL 5

GND 4 FB 5 FB2 6 VOUT 7 VOUT 8

C6 | C7 | VIN 13

MISO 2 MOSI 3 SCK 4 NSS 5 RESET 6 DIO5 7

DESIGN NOTE:
Jumper to select ONE_SHOT mode of the TPL5110
HIGH - works as timer
LOW - the TPL5110 turns on the MOSFET one time for
the programmed time interval. The next power on of the
MOSFET is enabled by the manual power ON.

PiRA-RTC-HAT-PCB.PrjPcb
PAGE2 - POWER, RTC, RPI.SchDoc





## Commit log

2017-09-22 add all
    [PAGE1 - CONTENTS.SchDoc, PAGE2 - POWER, RTC, RPI.SchDoc, PiRA-RTC-HAT-PCB.PcbDoc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]
2017-11-02 version v0.2
    [Bill of Materials production.xlsx, Bill of Materials-PiRA-RTC-HAT-PCB.xlsx, Bill of Materials-PiRA-RTC-HAT-PCB_farnell_27.09.2017.5pcs.xlsx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]
2017-11-06 version 0.2 manifacture
    [Bill of Materials production.xlsx, PAGE2 - POWER, RTC, RPI.SchDoc, PiRA-RTC-HAT-PCB.PcbDoc]
2017-11-06 new assembly file
    [Bill of Materials production.xlsx, PiRA-RTC-HAT-PCB.PcbDoc]
2017-11-17 add modification files for new version
    [Bill of Materials production.xlsx, Bill of Materials production_assembly_NS.xlsx, Bill of Materials production_farnell_06.11.2017.xlsx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]
2017-11-27 start new sch version v0.3
    [PAGE2 - POWER, RTC, RPI.SchDoc, PiRA-RTC-HAT-PCB.PcbDoc, PiRA-RTC-HAT-PCB.PrjPcb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]
2017-12-07 update pcb
    [PAGE2 - POWER, RTC, RPI.SchDoc, PiRA-RTC-HAT-PCB.PrjPcb, PiRA-RTC-HAT-PcbLib.PcbLib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]
2017-12-27 add new version v0.3
    [COM_pira_zero_v0.3.xlsx, COM_pira_zero_v0.3_farnell_12_12_2017.xlsx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]
2018-01-09 add docs for v0.3
    [PAGE2 - POWER, RTC, RPI.SchDoc, PiRA-RTC-HAT-PCB.PrjPcb]
